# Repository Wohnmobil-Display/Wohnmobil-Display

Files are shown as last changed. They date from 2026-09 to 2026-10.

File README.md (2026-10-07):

# Wohnmobil-Display – dein Wohnmobil immer im Blick

**Alles wird überwacht – und du bekommst eine Nachricht aufs Handy, wenn etwas nicht stimmt.**

Ein 7-Zoll-Touchdisplay, das rund um die Uhr auf dein Wohnmobil aufpasst:

- 🔋 **Spannung und Ladezustand** von Starter- und Aufbau-Batterie, jede einzelne Zelle des JK-BMS
- ☀️ **Solarertrag** vom Victron-Laderegler, heute und die letzten 7 Tage
- 💧 **Frisch- und Abwasser** – Warnung, bevor der Tank leer bzw. voll ist
- 🔥 **Gasflaschen** in Prozent – Warnung, bevor das Gas ausgeht
- 🌡️ **Temperaturen** innen, außen und im Kühlschrank – Warnung bei zu warm oder zu kalt
- 🚨 **Alarmanlage** mit Tür-, Fenster- und Bewegungsmeldern, **Rauch- und Gasmelder** rund um die Uhr
- 📱 **Push-Nachrichten per Telegram** für jede Warnung – du entscheidest, worüber du informiert werden willst
- 🗓️ **Tagesbericht per Telegram:** einmal am Tag zur Wunschzeit alle wichtigen Werte aufs Handy – Batterien, Tanks, Gas, Solar, Temperaturen, Alarm (ab dem nächsten Update)
- 📡 **Sensor offline oder Batterie schwach?** Auch das meldet das Display

Es ersetzt das originale Schaudt-Bedienteil **LT 100** und nutzt dessen **vorhandene Stecker und Kabel**.
Zum Ausprobieren läuft es **72 Stunden kostenlos und ohne Einschränkung**.

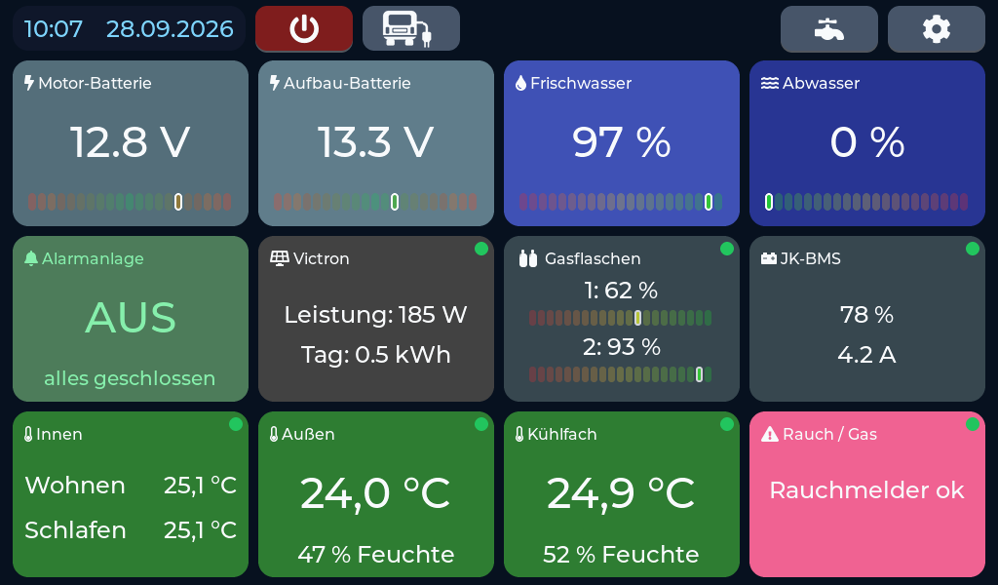
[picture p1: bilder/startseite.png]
Startseite


**Inhalt:** [Funktionen](#funktionen) · [Bedienung](#bedienung) · [Hardware](#hardware) · [Einkaufsliste](#einkaufsliste) ·
[Installation](#1-installation) · [Testzeit](#2-erster-start-testzeit) · [Freischalten](#3-freischalten) · [Updates](#4-updates)

## Funktionen

| Bereich | Was das Display kann |
|---|---|
| **Batterien** | Motor- und Aufbau-Batterie, JK-BMS mit allen 12 Zellen, Temperaturen und Ladezustand (Bluetooth) |
| **Solar** | Victron-MPPT-Laderegler: Leistung, Tagesertrag, Verlauf der letzten 7 Tage (Bluetooth) |
| **Wasser** | Frischwasser über den Original-Geber oder Ultraschall, Abwasser über die Original-Elektrodenstäbe |
| **Pumpe** | Wasserpumpe per Fingertipp ein/aus, automatisch gesperrt bei scharfer Alarmanlage |
| **Gas** | Zwei Gasflaschen mit Mopeka-Pro-Sensoren in Prozent (Bluetooth) |
| **Temperatur** | Innen (Wohn- und Schlafbereich), außen, Kühlschrank – über Zigbee-Sensoren oder fest verbaute Fühler |
| **Alarmanlage** | Bis zu 12 Zigbee-Sensoren (Tür/Fenster, Bewegung, Wasser), Nachtmodus, Verlassens-/Eingangszeit, PIN, Summer, Sirene |
| **Rauch / Gas** | Zigbee-Melder, rund um die Uhr überwacht |
| **Landstrom** | Anzeige, ob 230 V anliegen |
| **Push-Nachrichten** | Alarm, Grenzwerte, schwache Batterien, Sensor offline – per Telegram aufs Handy |
| **Tagesbericht** | täglich zur eingestellten Uhrzeit eine Zusammenfassung per Telegram, Inhalte frei wählbar (ab dem nächsten Update) |
| **Komfort** | Kachelnamen und Farben frei wählbar, Nachtabschaltung, Näherungssensor weckt das Display, Einstellen per Handy-Webseite |
| **Updates** | Neue Versionen per WLAN direkt am Display |

## Bedienung

Die komplette **[Bedienungsanleitung (PDF)](docs/Bedienungsanleitung.pdf)** zeigt jede Seite und jede Einstellung.

| Alarmanlage ein-/ausschalten | Victron / Solar mit 7-Tage-Verlauf |
|---|---|
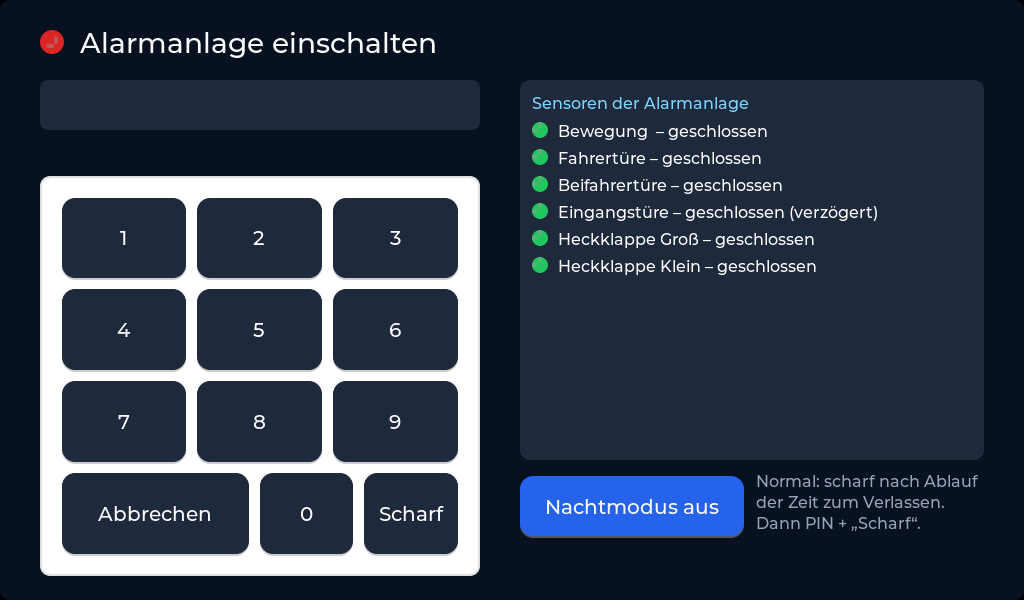
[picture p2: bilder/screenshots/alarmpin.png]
PIN-Dialog
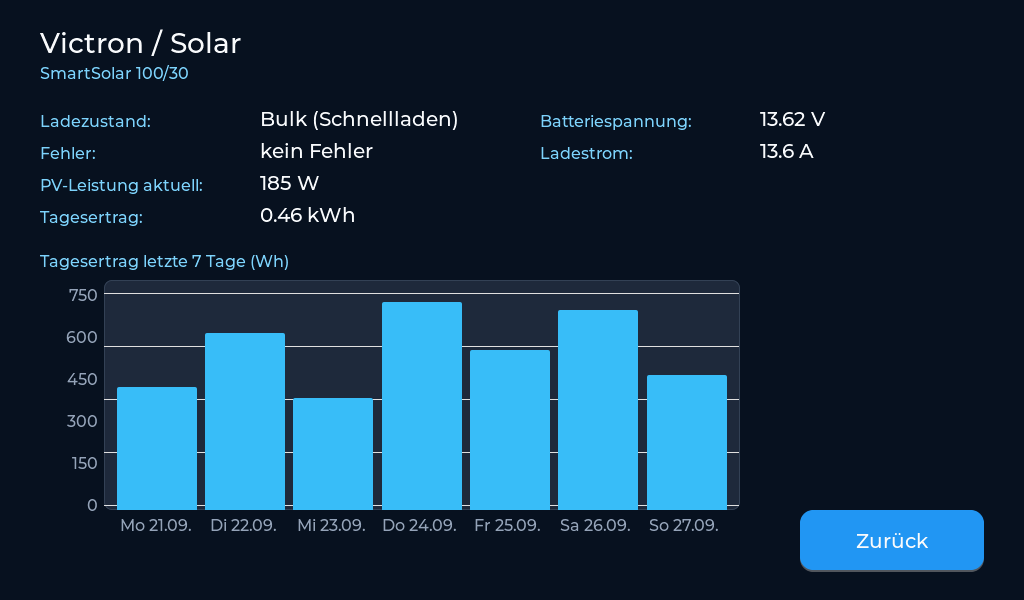
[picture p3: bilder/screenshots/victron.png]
Victron
|  |  |
| **JK-BMS mit Zellspannungen** | **Zigbee-Geräte** |
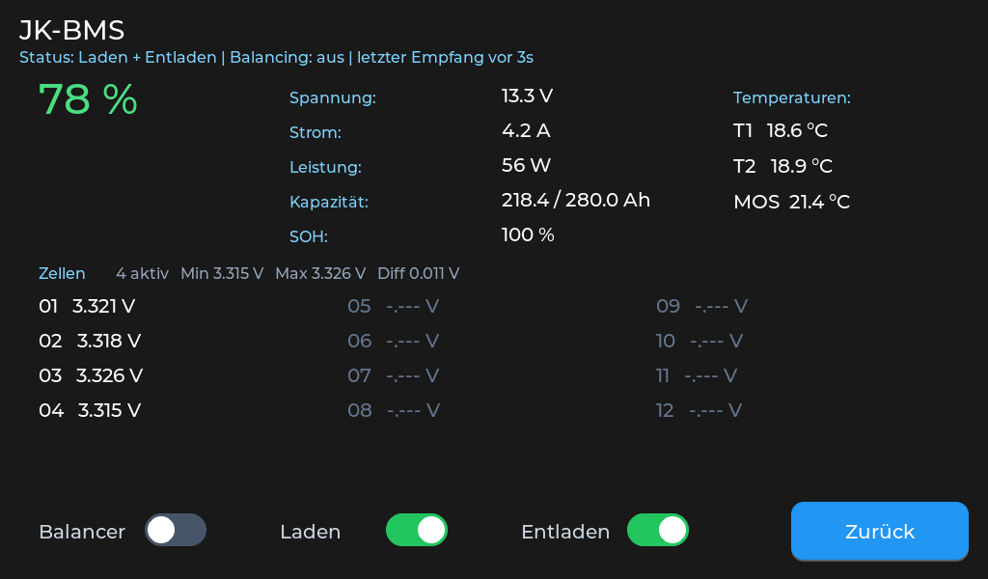
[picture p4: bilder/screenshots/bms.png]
JK-BMS
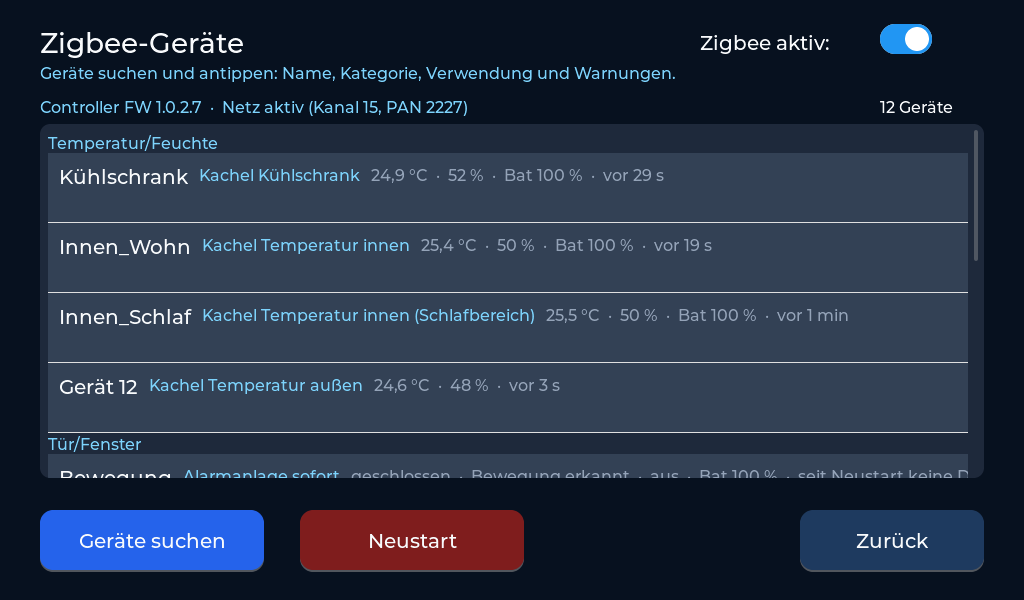
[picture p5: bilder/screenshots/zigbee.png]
Zigbee
|  |  |
| **Setup Alarmanlage** | **Setup Display** |
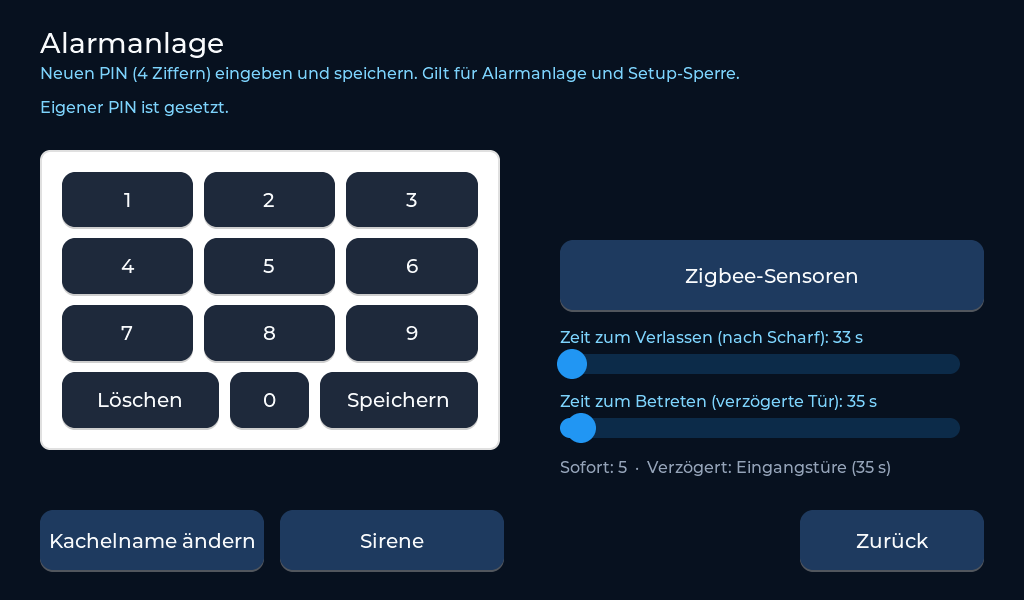
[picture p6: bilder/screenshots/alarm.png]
Setup Alarmanlage
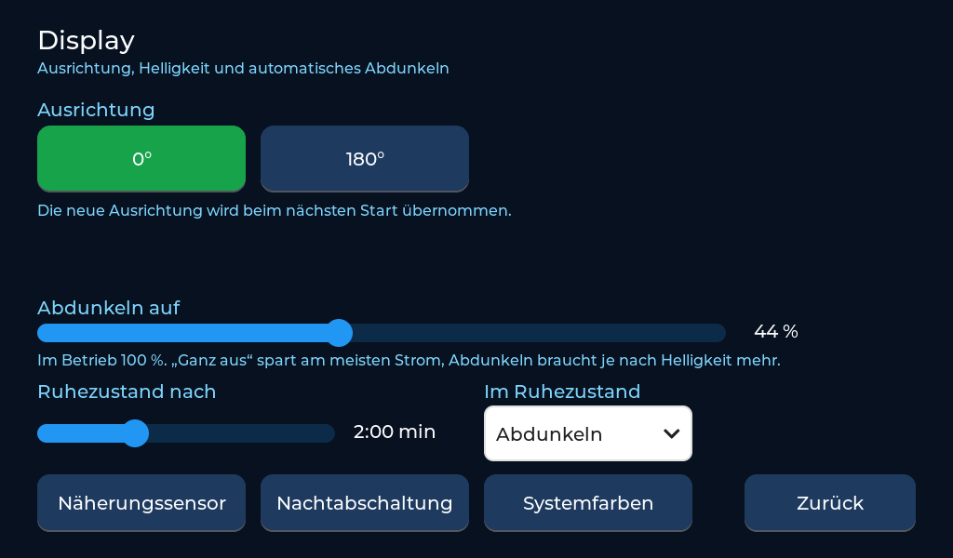
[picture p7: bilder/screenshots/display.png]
Setup Display
|  |  |
| **Setup Push-Nachrichten** | **Tagesbericht per Telegram** |
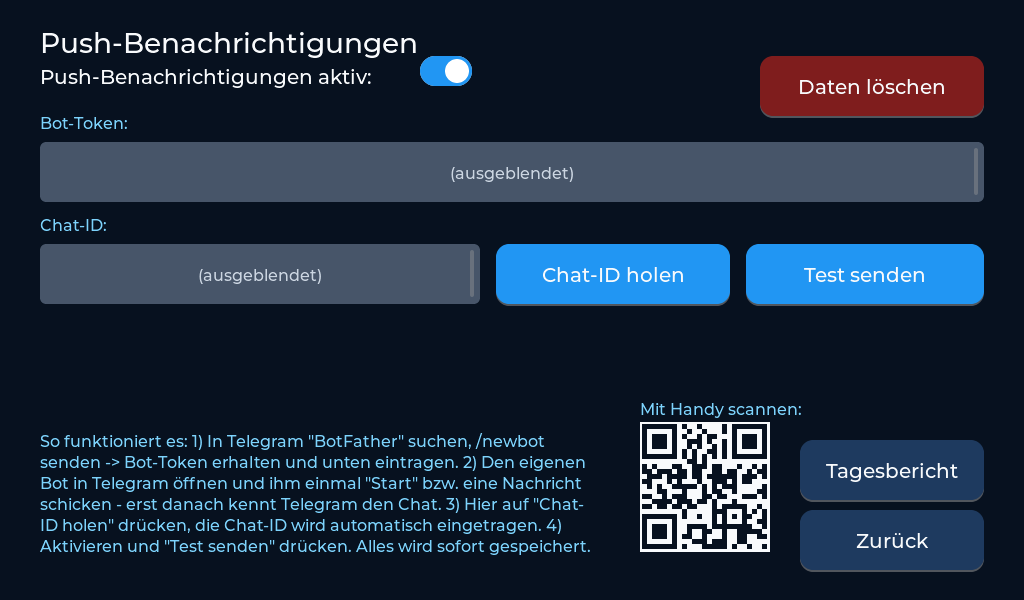
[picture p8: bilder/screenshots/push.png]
Setup Push
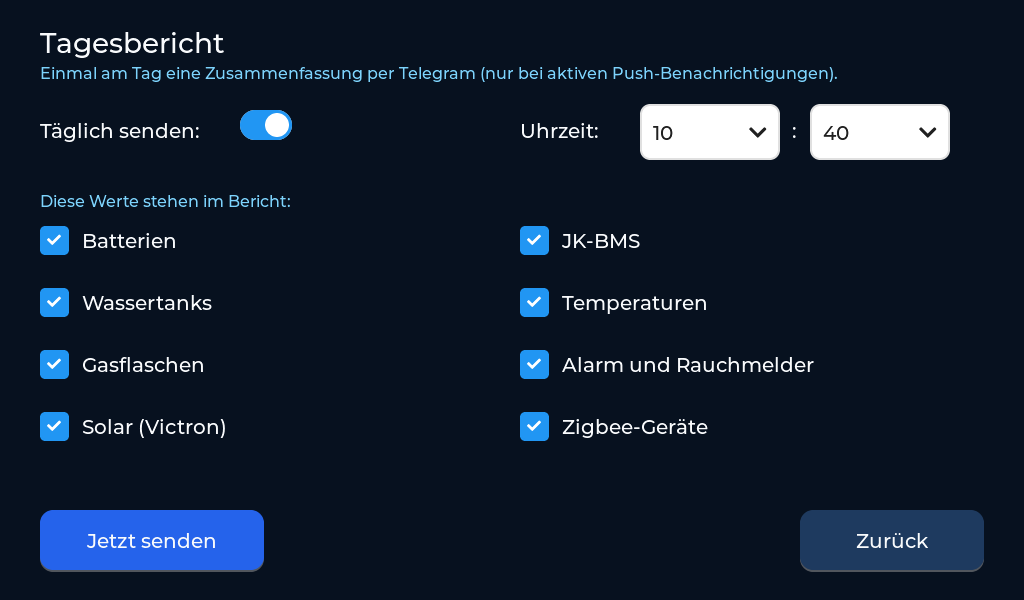
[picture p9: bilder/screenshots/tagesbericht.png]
Tagesbericht
|  |  |
| **Setup Victron-Laderegler** | |
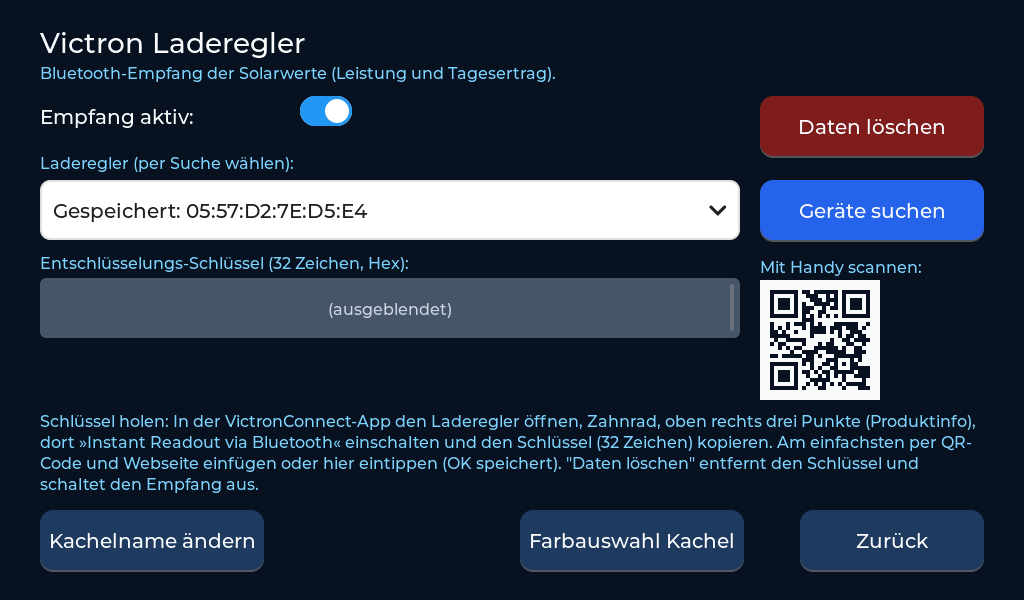
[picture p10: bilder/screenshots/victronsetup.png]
Setup Victron
|  | |

*Victron- und BMS-Seite mit Beispielwerten; Bot-Token, Chat-ID und Victron-Schlüssel sind im Bild ausgeblendet.*

- **Startseite:** 12 Kacheln, oben Uhrzeit, Landstrom, Störmeldungen, Wasserpumpe und Setup.
- **Rote Kachel:** ein eingestellter Grenzwert ist verletzt (z. B. Frischwasser fast leer).
- **Antippen** öffnet Detailseiten (Solar, BMS, Temperaturen) bzw. die PIN-Eingabe der Alarmanlage.
- **Setup:** keine Speichern-Taste – alles wird sofort gespeichert.

## Hardware

Systemübersicht

Das System besteht aus dem **Display** und der **Steuerplatine** – beide sind nötig.
Die **Relaisplatine** für die Wasserpumpe ist eine Erweiterung, die man weglassen kann.

- **Display:** Waveshare ESP32-S3-Touch-LCD-7B (7 Zoll, 1024×600, WLAN, Bluetooth).
  Bluetooth-Geräte (Victron, Mopeka, JK-BMS) empfängt es direkt.
- **3D-Druckteile** im Ordner [`druck/`](druck/): **Rahmen für das Display** (ersetzt das LT 100 im vorhandenen Ausschnitt, mit oder ohne Näherungssensor), **Halter für Türkontakte** (Sensor und Magnet, verschiedene Sockelhöhen) und **Gehäuse** für Steuer- und Relaisplatine.

### Steuerplatine – notwendig

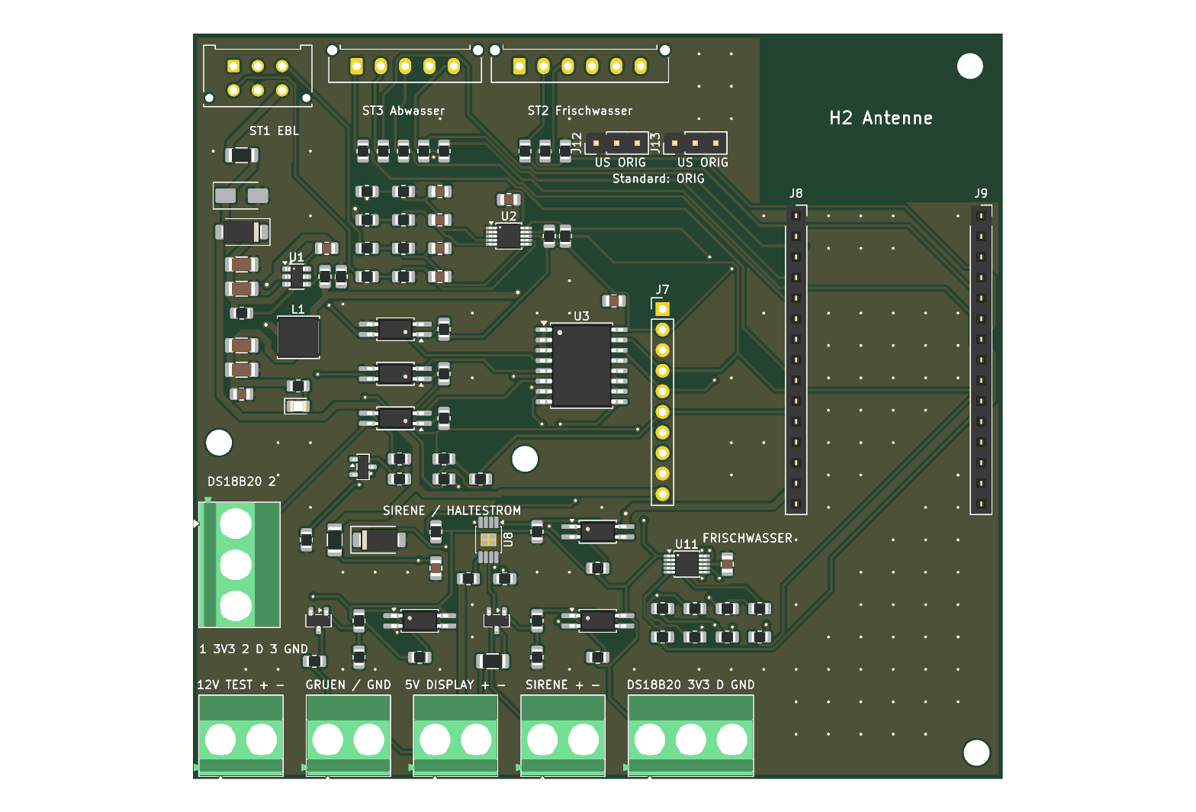
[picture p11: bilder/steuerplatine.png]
Steuerplatine


Die Steuerplatine ist die Verbindung zwischen Display und Fahrzeug. Sie sitzt dort, wo vorher das LT 100 war,
und bekommt **die vorhandenen Original-Stecker** – es muss kein neues Kabel durchs Fahrzeug gezogen werden.
Auf ihr steckt das **ESP32-H2-Board**, das die Messwerte erfasst und das **Zigbee-Funknetz** betreibt.
Mit dem Display ist sie über **ein USB-Kabel** verbunden.

| Anschluss | Was angeschlossen wird |
|---|---|
| **ST1 – EBL** (Original-Stecker) | Stromversorgung 12 V, Hauptschalter **EIN/AUS**, 12-V-Kontrolle, **Landstrom** (230 V liegt an) |
| **ST2 – Frischwasser** (Original-Stecker) | Originaler Tankgeber (Stabsonde) **oder** Ultraschallsensor – umschaltbar per Steckbrücke |
| **ST3 – Abwasser** (Original-Stecker) | Originale Elektrodenstäbe (25 / 50 / 75 / 100 %) |
| **Klemme GRÜN** | Freie grüne Ader im Panelkabel: misst die **Starterbatterie** und schaltet die Relaisplatine |
| **Klemme 5V DISPLAY** | Versorgt das Display – ein eigenes Netzteil ist nicht nötig |
| **Klemme SIRENE** | Alarmsirene (überwacht auf Kurzschluss und offene Leitung) |
| **Klemmen DS18B20** | Fest verbaute Temperaturfühler (z. B. innen, Kühlschrank) |
| **USB** | Verbindung zum Display |

Gemessen werden Starter- und Aufbau-Batterie, 12-V-Kontrolle und Landstrom.
**Ohne Steuerplatine** zeigt das Display nur die Bluetooth-Geräte – Tanks, Hauptschalter, Landstrom,
Pumpe und alle Zigbee-Sensoren (Alarmanlage, Rauchmelder, Temperaturen) funktionieren dann nicht.

**Frischwasser mit Ultraschallsensor** – die vorhandene Leitung der Füllstandsstäbe wird weiterbenutzt,
am Tank wird der alte Stecker abgeschnitten und die Adern nach Farbe an die Sensorplatine gelötet,
auf der Steuerplatine werden nur die beiden Steckbrücken J12/J13 auf „US“ gesteckt:

Ultraschallsensor an der Steuerplatine

### Relaisplatine für die Frischwasserpumpe – optional

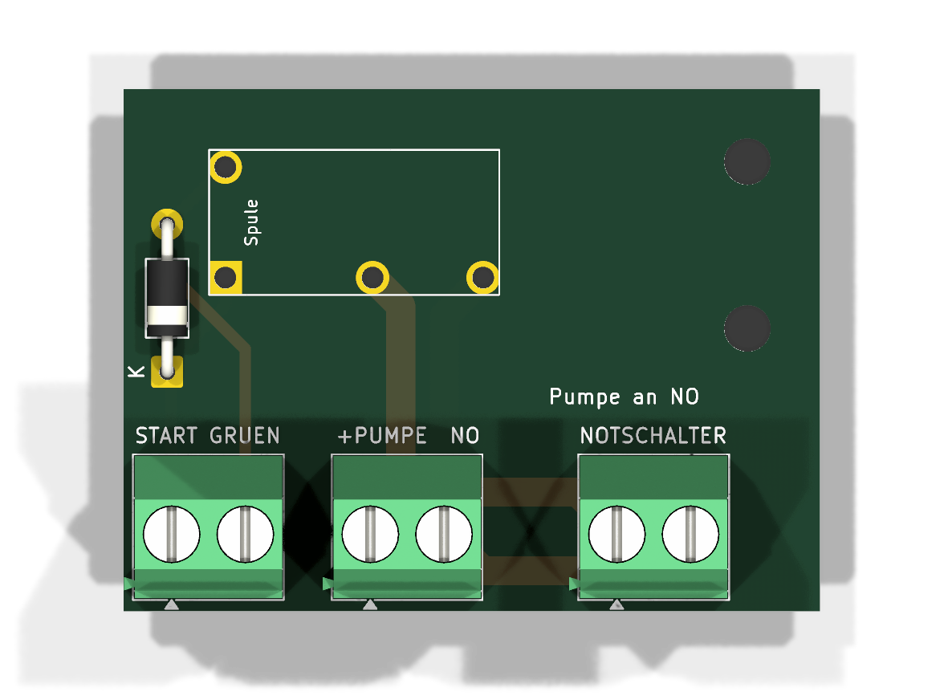
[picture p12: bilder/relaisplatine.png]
Relaisplatine


Beim originalen LT 100 lässt sich die Wasserpumpe nicht schalten – hier schon:

- **Pumpe per Fingertipp ein/aus** über das Wasserhahn-Symbol oben auf der Startseite.
- **Automatisch aus, wenn die Alarmanlage scharf ist** – kein Wasser läuft unbemerkt, während du weg bist.
- **Anschluss für einen Notschalter**: überbrückt das Relais, falls einmal etwas nicht funktioniert – die Pumpe läuft dann wie früher.
- Die Platine wird am EBL in die Plus-Leitung der Pumpe eingesetzt und über die grüne Ader von der Steuerplatine geschaltet.

**Keine Relaisplatine?** Unter *Setup → Allgemein → Wasserpumpe (Relaisplatine)* ausschalten –
dann verschwinden das Wasserhahn-Symbol und alle Pumpen-Meldungen, alles andere läuft weiter.

**Die Original-Stecker werden einfach umgesteckt – kein neues Kabel durchs Fahrzeug:**

| LT 100 mit den Original-Steckern | Stecker abgezogen |
|---|---|
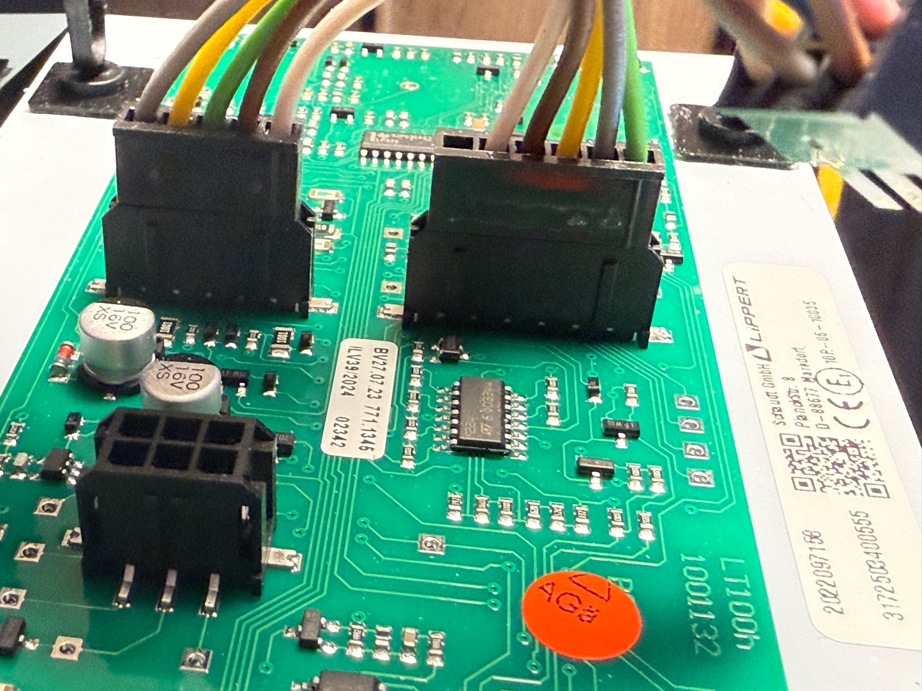
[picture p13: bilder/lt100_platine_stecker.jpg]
LT 100 Platine
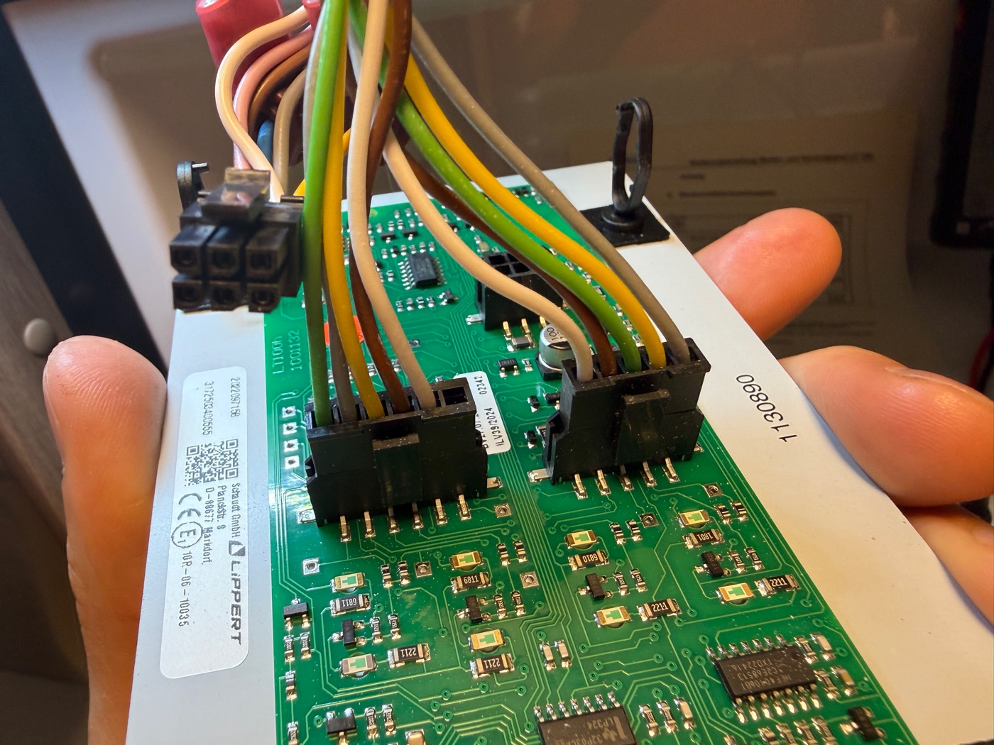
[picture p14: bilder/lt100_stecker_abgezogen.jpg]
Stecker abgezogen
|  |  |

| Kabel zum EBL (ST1) | EBL 31, Block 3 „Instr.-Tafel“ |
|---|---|
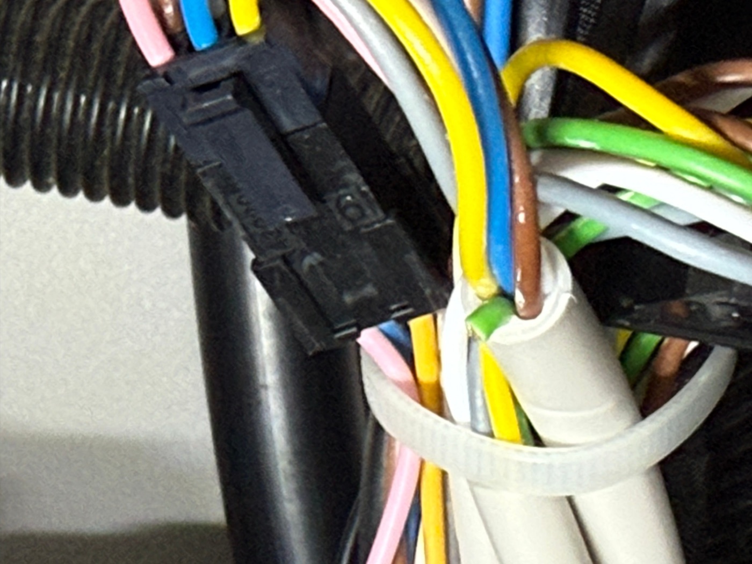
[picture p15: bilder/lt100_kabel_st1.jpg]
ST1
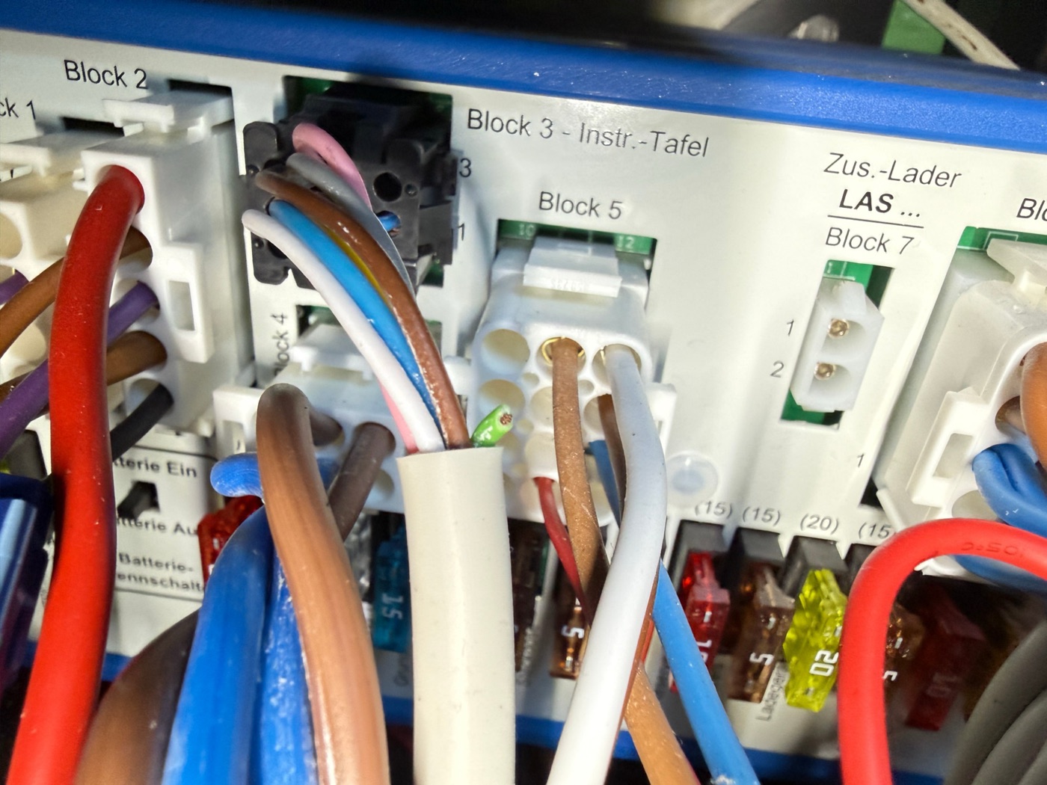
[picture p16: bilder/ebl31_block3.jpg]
EBL 31
|  |  |

Anschlüsse am Display:

Anschlüsse am Display

**Summer und Näherungssensor** kommen direkt an das Display (Buchsen J8 und H1). Die Stecker mit Kabel
sind vorhanden – nur die beiden Bauteile an die Kabelenden anlöten:

Summer und Näherungssensor am Display

## Einkaufsliste

| Teil | Wofür | Link |
|---|---|---|
| Waveshare ESP32-S3-Touch-LCD-7B (7 Zoll, 1024×600) | Das Display | [Amazon\*](https://www.amazon.de/dp/B0FG354VCN?tag=wohnmobildisp-21) |
| ESP32-H2-DevKitM-1 (N4) | Zigbee und Steuerplatine | [Amazon\*](https://www.amazon.de/dp/B0D8XR48LF?tag=wohnmobildisp-21) |
| Ultraschallsensor JSN-SR04M-2 / AJ-SR04M / A02YYPWM (wasserdicht) | Frischwasser (optional, statt Original-Geber) – funktioniert ohne Löten, wird automatisch erkannt | [Amazon\*](https://www.amazon.de/dp/B0FPPTTHTJ?tag=wohnmobildisp-21) |
| frient Smoke Alarm (Zigbee-Rauchmelder mit Sirene) | Rauchmelder, auch als Alarm-Sirene nutzbar | [Amazon\*](https://www.amazon.de/dp/B08WXV3G8P?tag=wohnmobildisp-21) |
| SONOFF SNZB-02B (Zigbee-Temperatur/Luftfeuchte) | Temperatur innen, außen, Kühlschrank | [Amazon\*](https://www.amazon.de/dp/B0H4QJQFKM?tag=wohnmobildisp-21) |
| SONOFF SNZB-04P (Zigbee-Tür-/Fensterkontakt) | Alarmanlage | [Amazon\*](https://www.amazon.de/dp/B0DD3SQYV9?tag=wohnmobildisp-21) |
| SONOFF SNZB-03P (Zigbee-Bewegungsmelder) | Alarmanlage | [Amazon\*](https://www.amazon.de/dp/B0C1GB4DVR?tag=wohnmobildisp-21) |
| Mopeka Pro (Ultraschallsensor mit Magnet) | Gasflaschen-Füllstand (optional) | [Amazon\*](https://www.amazon.de/dp/B0GCD1Q4HP?tag=wohnmobildisp-21) |
| VL53L0X-Näherungssensor (2 Stück) | Display wird hell, wenn jemand davor steht (optional) – getestet, funktioniert sofort | [Amazon\*](https://www.amazon.de/dp/B0FPQRKR9T?tag=wohnmobildisp-21) |
| Steckverbinder-Set 6-polig MATE-N-LOK (Kalitec KALI-1106, 6,35 mm, inkl. Crimpkontakte und Dichtungen, bis 19 A) | 12-V-Dauerspannung am EBL-Stecker Block 5 Pin 3 abgreifen (dort liegt auch der Wassertank-Anschluss): Crimpkontakt auf die Ader, in den freien Platz am EBL-Stecker einstecken | [Amazon\*](https://www.amazon.de/dp/B0DP58HVVM/?tag=wohnmobildisp-21) |
| USB-C-Datenkabel (240 W, Set: 1 m + 1 m + 1,5 m + 1,5 m) | Verbindung Display ↔ Steuerplatine und Anschluss am Computer – reines Ladekabel funktioniert nicht | [Amazon\*](https://www.amazon.de/dp/B0GX5WF5B9/?tag=wohnmobildisp-21) |
| Schrauben M3 × 8 mm (100 Stück, Edelstahl, Flachkopf, vollgewinde) | Montage | [Amazon\*](https://www.amazon.de/dp/B0FHGSGFY4/?tag=wohnmobildisp-21) |

\* Werbelink: Als Amazon-Partner verdiene ich an qualifizierten Verkäufen. Für dich ändert sich am Preis nichts.

## 1. Installation

Die Firmware wird direkt im Browser installiert – ohne Download und ohne Zusatzprogramm.

**Du brauchst:**
- ein USB-Datenkabel (ein reines Ladekabel funktioniert nicht),
- einen Computer mit **Google Chrome** oder **Microsoft Edge**,
- kein anderes Programm, das gerade auf den USB-Anschluss zugreift (z. B. Arduino IDE, serieller Monitor).

Es werden **zwei Geräte** installiert – beide auf derselben Installer-Seite, jedes mit eigenem Knopf:

| Gerät | Anschluss am Computer | Direkt zum Knopf |
|---|---|---|
| **① Display** (Waveshare 7 Zoll) | USB-C-Buchse **„UART1“** am Display (Schalter SW1 auf „UART1“) | **[Display installieren](https://wohnmobil-display.github.io/Wohnmobil-Display/#display)** |
| **② Steuerplatine** (ESP32-H2-Board) | Buchse **„USB“** am H2-Board (nicht „UART“), einmal **vor dem Einbau** | **[Steuerplatine installieren](https://wohnmobil-display.github.io/Wohnmobil-Display/#steuerplatine)** |

Welche Buchse wofür – Display-Rückseite und H2-Board

Display und Steuerplatine verbinden

> **Wichtig – Jumper J5 am H2-Board:** Die kleine Steckbrücke (Jumper) muss auf den beiden Stiften **J5** stecken.
> Ohne sie bekommt der Chip keinen Strom – er wird am Computer nicht erkannt und läuft auch auf der Steuerplatine nicht.
> Liegt der Jumper lose in der Packung, einfach aufstecken.

**So geht's (für beide Geräte gleich):**
1. Link oben anklicken – die Installer-Seite öffnet sich beim passenden Knopf.
2. Gerät per USB anschließen und auf **Display installieren** bzw. **Steuerplatine installieren** klicken.
3. Im Fenster den Eintrag des Geräts wählen (z. B. „USB JTAG/serial debug unit“ oder „USB Single Serial“) und auf **Verbinden** klicken.
4. Installation bestätigen und warten, bis sie fertig ist. Kabel nicht abziehen, Browser nicht schließen.
5. Das Gerät startet danach von selbst neu. Falls nicht: kurz vom Strom trennen und wieder anschließen.

Die Steuerplatine muss nur **ein einziges Mal** so installiert werden. Spätere Updates spielt das Display
selbst über das USB-Kabel auf (siehe [Updates](#4-updates)).

> Wird kein Gerät angezeigt, probiere ein anderes Kabel oder einen anderen USB-Anschluss.
> Stecke das Gerät kurz ab und wieder an und wähle dann den neu erschienenen Eintrag.

## 2. Erster Start: Testzeit

Beim ersten Start zeigt das Display den Bildschirm **Freischaltung** mit zwei Werten:

- **Chip-ID**, z. B. `AA:BB:CC:DD:EE:FF`
- **Freigabecode**, z. B. `1234`

Darunter steht die fertige Zeile zum Freischalten, z. B.:

```
AA:BB:CC:DD:EE:FF 1234
```

Mit **„Test starten (72 Std.)“** kannst du das Display 72 Betriebsstunden lang kostenlos und uneingeschränkt nutzen.
Gezählt wird nur die Zeit, in der das Display eingeschaltet ist. Die restliche Testzeit steht oben in der Kopfzeile.
Nach Ablauf zeigt das Display nur noch den Freischalt-Bildschirm.

## 3. Freischalten

Das Wohnmobil-Display ist ein privat entwickeltes Hobbyprojekt. Für die dauerhafte Nutzung ist ein persönlicher,
6-stelliger **Freischaltcode** nötig. Er kostet einmalig **29 €** und gilt für immer – auch nach Neustarts und Updates.

1. Öffne den PayPal-Link: **[paypal.com/ncp/payment/MHXFBPU9TVV2L](https://www.paypal.com/ncp/payment/MHXFBPU9TVV2L)**
2. Trage im Feld **„Chip-ID + Freigabecode“** die Zeile vom Display ein – genau so, wie sie dort steht:
   `AA:BB:CC:DD:EE:FF 1234`
3. Nach Eingang der Zahlung bekommst du den Freischaltcode per E-Mail, in der Regel **innerhalb von 24 Stunden**.
4. Gib den Code am Display ein und bestätige mit **OK**. Fertig – das Display ist dauerhaft freigeschaltet.

Den Freischalt-Bildschirm erreichst du während der Testzeit auch über **Setup → Allgemein → Freischaltung**.

> Feld beim Bezahlen vergessen? Schick die Zeile einfach an **wohnmobil.display@gmail.com**.
>
> Nach jeder dritten falschen Eingabe wird die Eingabe für einige Stunden gesperrt – den Code bitte genau übernehmen.

## 4. Updates

Freigeschaltete Displays holen neue Versionen selbst über WLAN – **für das Display und für die Steuerplatine**:
**Setup → Allgemein → Update → Installieren.**
Die Steuerplatine wird dabei über das USB-Kabel vom Display aus aktualisiert – nichts muss ausgebaut werden.
Deine Einstellungen bleiben dabei erhalten. Startet eine neue Version einmal nicht richtig,
kehrt das Display automatisch zur vorherigen Version zurück.

Was sich geändert hat, steht bei den [Versionen (Releases)](https://github.com/Wohnmobil-Display/Wohnmobil-Display/releases).

## Hilfe bei Verbindungsproblemen

- Nur Chrome oder Edge verwenden.
- Ein anderes USB-Kabel und einen anderen USB-Anschluss probieren.
- Alle Programme schließen, die den USB-Anschluss benutzen könnten.
- Display kurz abziehen und wieder anschließen, Installer-Seite neu laden.

## Manuelle Installation

Falls die Installer-Seite nicht funktioniert: Unter [Releases](https://github.com/Wohnmobil-Display/Wohnmobil-Display/releases)
liegen zwei Dateien, die mit einem eigenen Flash-Programm jeweils an **Adresse 0x0** geschrieben werden:
- `Wohnmobil-Display-FULL.bin` → Display
- `Steuerplatine-H2-FULL.bin` → Steuerplatine (ESP32-H2, Buchse „USB“)

Die Dateien ohne „FULL“ sind nur für Updates gedacht.

## Hinweis

Das Wohnmobil-Display ist ein privates DIY-Projekt ohne Firma dahinter und steht in keiner Verbindung zu Schaudt,
Waveshare, Victron, Mopeka oder anderen Herstellern der unterstützten Geräte. Die Nutzung erfolgt auf eigene Verantwortung.

Kontakt: **wohnmobil.display@gmail.com**

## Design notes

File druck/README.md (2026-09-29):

# Druckdateien (3D-Druck)

| Teil | Dateien | Außenmaß (B × T × H) |
|---|---|---|
| Gehäuse Steuerplatine V2 | [Unterschale](steuerplatine_v2_unterschale.stl) · [Deckel](steuerplatine_v2_deckel.stl) | 127 × 112 × 34 mm (mit Laschen) |
| Gehäuse Relaisplatine V2 | [Unterschale](relaisplatine_v2_unterschale.stl) · [Deckel](relaisplatine_v2_deckel.stl) | 75 × 56 × 30 mm (mit Laschen) |
| Rahmen für das Display (7 Zoll) – ersetzt das alte LT-100-Panel | [mit Näherungssensor](display_rahmen_mit_sensor.stl) · [ohne Sensor](display_rahmen_ohne_sensor.stl) | 193 × 123 × 27 mm / 193 × 111 × 27 mm |
| Türkontakt-Halter Standard, 2-mm-Boden (nur Kleben) | [Sensorhalter](tuerkontakt_sensorhalter_standard.stl) · [Magnethalter](tuerkontakt_magnethalter_standard.stl) | 94 × 15 × 28 mm / 50 × 9 × 16 mm |
| Türkontakt-Halter mit 5 mm Abstand (Kleben oder Schrauben) | [Sensorhalter](tuerkontakt_sensorhalter_5mm.stl) · [Magnethalter](tuerkontakt_magnethalter_5mm.stl) | 94 × 20 × 28 mm / 50 × 14 × 16 mm |
| Türkontakt-Halter mit 10 mm Abstand (Kleben oder Schrauben) | [Sensorhalter](tuerkontakt_sensorhalter_10mm.stl) · [Magnethalter](tuerkontakt_magnethalter_10mm.stl) | 94 × 25 × 28 mm / 50 × 19 × 16 mm |

**Drucken:** PLA oder PETG, 0,2 mm Schichthöhe, 3 Wände. Die Gehäuse und Türkontakt-Halter gehen ohne Stützmaterial
(Unterschale mit dem Boden nach unten, Deckel mit der Oberseite nach unten). **Der Rahmen für das Display braucht Stützstruktur.**
Die Kabelschlitze der Gehäuse sind oben offen, die Zungen am Deckel schließen sie bis auf den Kabelspalt.

**Montage:**
- Platine mit M3-Schrauben (selbstschneidend, ca. 8 mm) auf die Stehbolzen schrauben.
- Deckel mit 4 × M3 (ca. 16 mm) in die Eckpfosten schrauben.
- Gehäuse über die seitlichen Laschen (Loch 4,5 mm) an Wand oder Möbel schrauben.

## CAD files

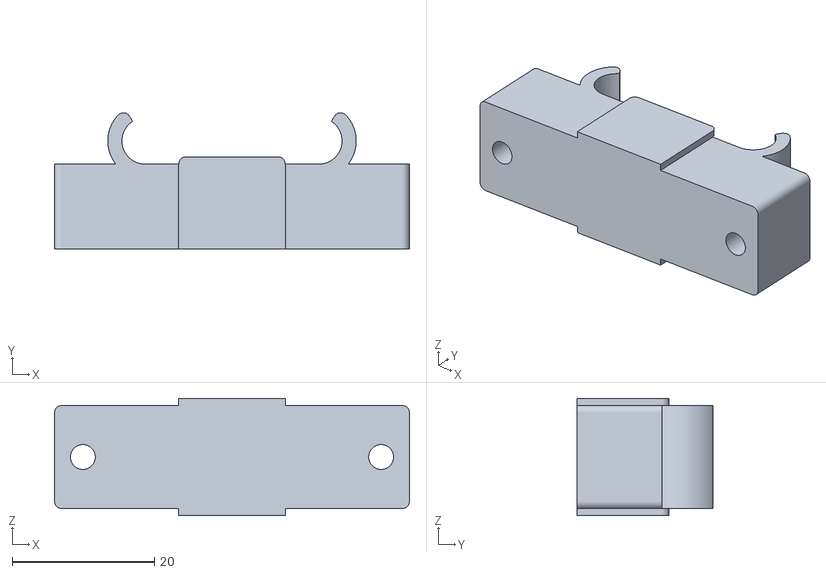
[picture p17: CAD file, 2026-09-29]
druck/tuerkontakt_magnethalter_10mm.stl
50.0 x 19.2 x 16.5

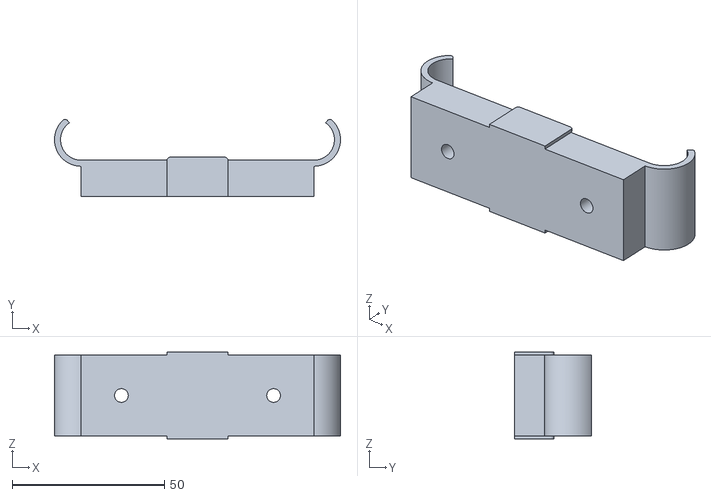
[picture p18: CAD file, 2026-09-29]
druck/tuerkontakt_sensorhalter_10mm.stl
94.0 x 25.4 x 28.5

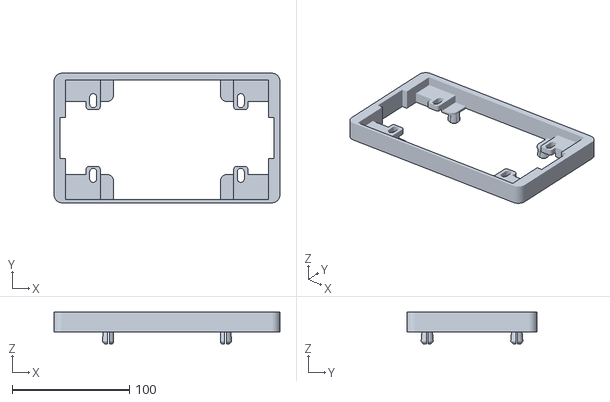
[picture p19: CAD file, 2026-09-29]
druck/display_rahmen_ohne_sensor.stl
193.0 x 110.8 x 27.0

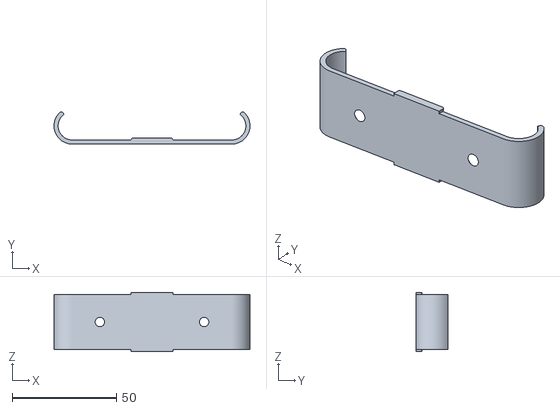
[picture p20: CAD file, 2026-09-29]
druck/tuerkontakt_sensorhalter_standard.stl
94.0 x 15.4 x 28.5

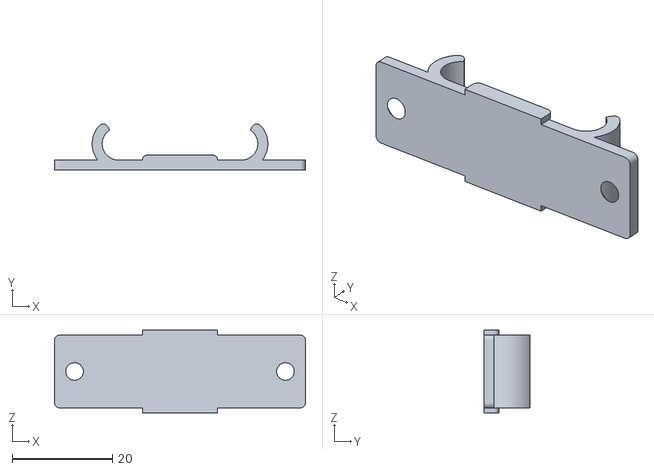
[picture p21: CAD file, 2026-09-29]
druck/tuerkontakt_magnethalter_standard.stl
50.0 x 9.21 x 16.5

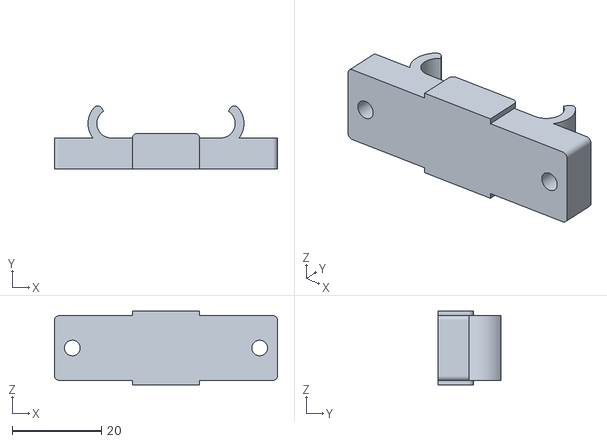
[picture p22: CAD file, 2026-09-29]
druck/tuerkontakt_magnethalter_5mm.stl
50.0 x 14.2 x 16.5

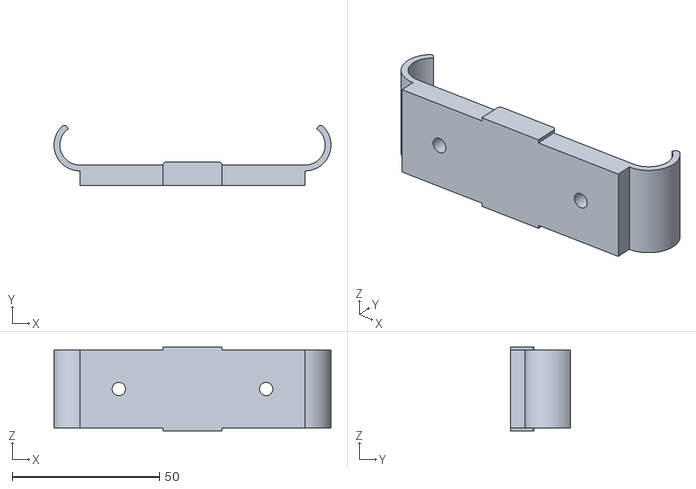
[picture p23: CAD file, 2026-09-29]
druck/tuerkontakt_sensorhalter_5mm.stl
94.0 x 20.4 x 28.5

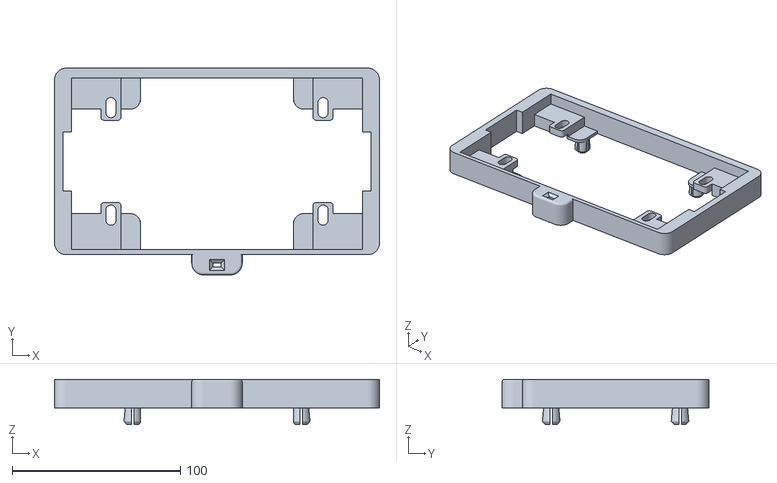
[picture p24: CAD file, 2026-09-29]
druck/display_rahmen_mit_sensor.stl
193.0 x 122.8 x 27.0

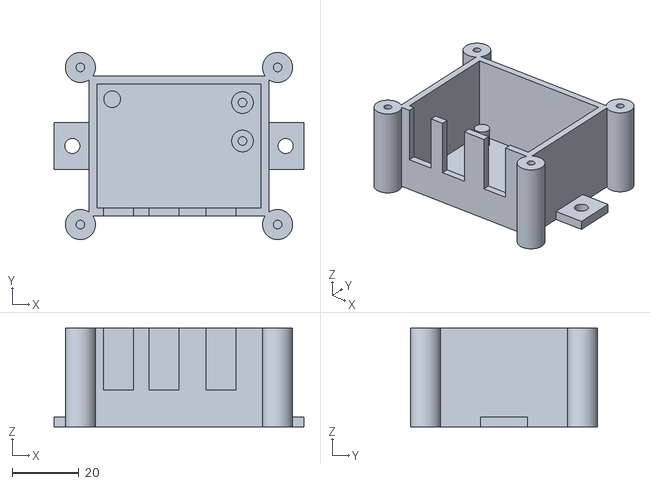
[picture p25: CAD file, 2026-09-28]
druck/relaisplatine_v2_unterschale.stl
74.8 x 56.0 x 29.6

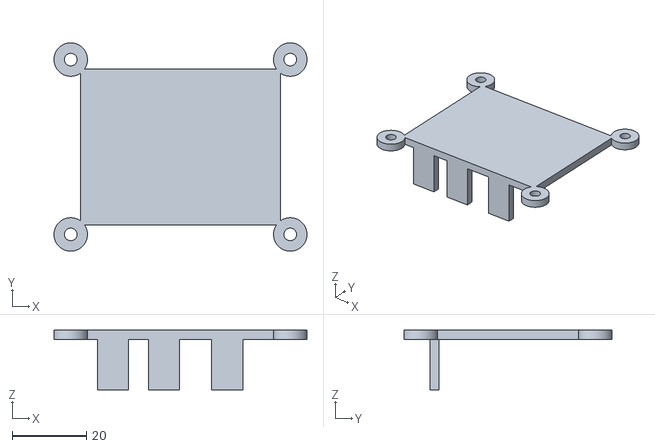
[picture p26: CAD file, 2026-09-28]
druck/relaisplatine_v2_deckel.stl
68.0 x 56.0 x 16.0

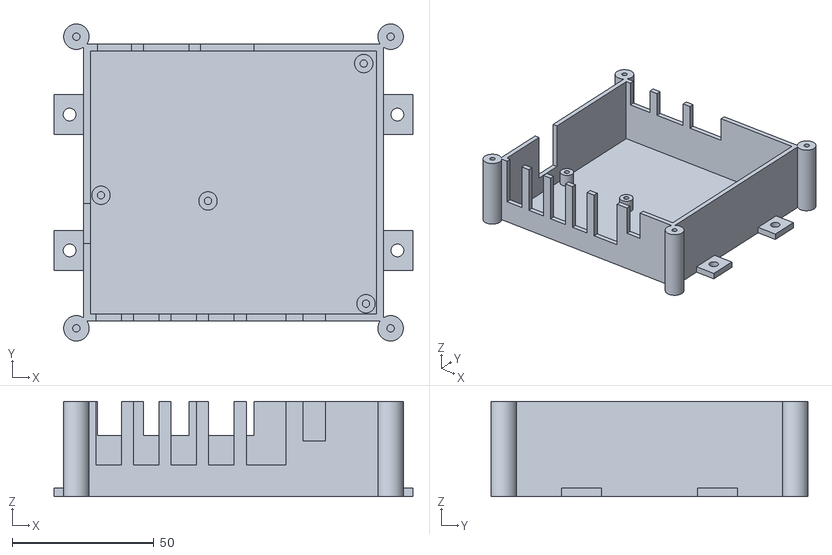
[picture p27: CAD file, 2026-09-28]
druck/steuerplatine_v2_unterschale.stl
126.8 x 112.0 x 33.6

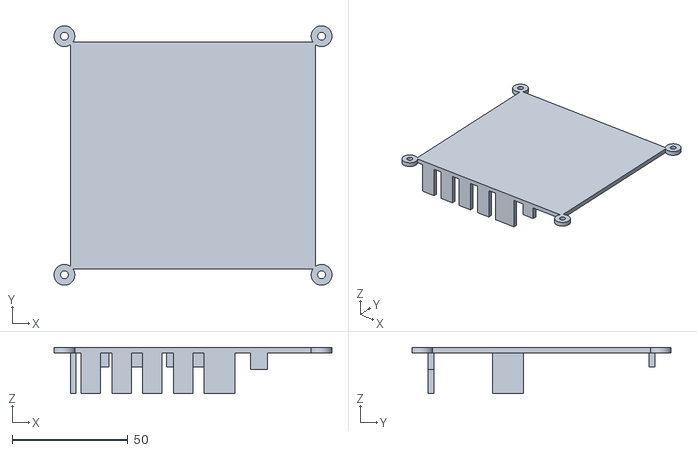
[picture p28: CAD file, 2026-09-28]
druck/steuerplatine_v2_deckel.stl
120.0 x 112.0 x 20.0

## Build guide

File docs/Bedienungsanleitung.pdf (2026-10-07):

# Wohnmobil-Display – Bedienungsanleitung

Bedienung aller Funktionen des 7-Zoll-Touch-Displays. Stand: 28.09.2026 (Display 1.0.8, Steuerplatine 1.0.3.0)

1. Erster Start und WLAN
2. Die Startseite
3. Alarmanlage
4. Das Setup-Menü – Grundregeln
5. Setup: Kacheln
6. Setup: System
7. Push-Nachrichten aufs Handy
8. Einstellen per Handy (Webseite)
9. Display ausschalten
10. Hilfe bei Problemen
11. Testzeit und Freischaltung
12. Updates
13. Druckteile (3D-Druck)

## 1. Erster Start und WLAN

1. Nach dem Einschalten sucht das Display nach WLAN-Netzen und zeigt sie als Liste an.
2. Netz antippen, das Passwort über die Bildschirmtastatur eingeben und Verbinden drücken. Mit der Taste äöü erreichst du Umlaute und Sonderzeichen.
3. Nach der Verbindung wechselt das Display automatisch zur Startseite. Das WLAN wird gespeichert und beim nächsten Start selbst verbunden.

Datum und Uhrzeit kommen automatisch aus dem Internet. Ohne WLAN zeigt die Uhr „--:--“.
Wird das WLAN nicht gefunden, erscheint oben im roten Meldungsfeld „Kein WLAN“. Ein anderes Netz richtest du unter Setup → WLAN-Einstellungen ein, dort gibt es auch WLAN löschen .

## 2. Die Startseite

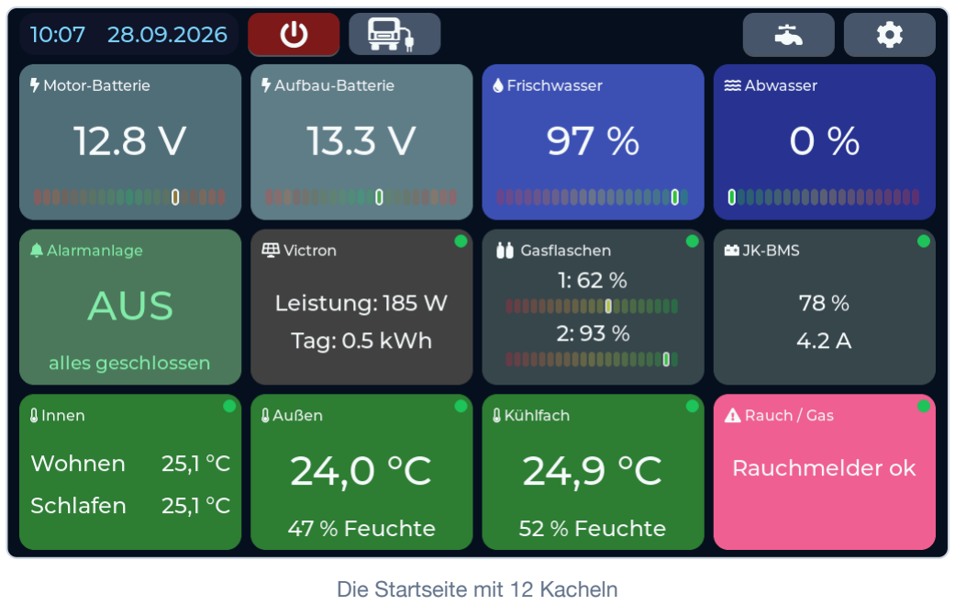
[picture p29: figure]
Die Startseite mit 12 Kacheln

Die Kopfzeile enthält von links nach rechts:

Feld | Bedeutung
Uhrzeit und Datum | aus dem Internet (WLAN)
rote Taste ⏻ | Display ausschalten (Abschnitt 9)
Landstrom (Wohnmobil mit Stecker) | gelb = 230-V-Landstrom liegt an (Netzkontrolle vom EBL), grau = kein Landstrom oder Steuerplatine nicht erreichbar
rotes Meldungsfeld | erscheint nur bei einer Störung, z. B. „Steuerplatine nicht erreichbar“, „Kein WLAN“, „Sensor offline: Name“, „Sirene: Kurzschluss oder Leitung offen“. Mehrere Meldungen wechseln alle 3 s, mit „(1/3)“.
Wasserhahn | Wasserpumpe: grün = frei, grau = gesperrt. Antippen fragt „Pumpe ein/aus?“. Bei scharfer Alarmanlage ist die Pumpe automatisch gesperrt.
Zahnrad | Setup

Darunter liegen 12 Kacheln:

Motor-Batterie Spannung | Aufbau-Batterie Spannung | Frischwasser Füllstand % | Abwasser Füllstand %
Alarmanlage Zustand, Tippen = PIN | Victron / Solar Leistung, Tagesertrag | Gas Flasche 1 und 2 in % | JK-BMS Ladezustand, Strom
Temperatur innen °C, Luftfeuchte; mit 2 Sensoren Wohnen/Schlafen | Temperatur außen °C, Luftfeuchte | Kühlschrank °C | Rauch / Gas Melder-Zustand

Rote Kachel: Ein eingestellter Grenzwert ist verletzt, zum Beispiel Frischwasser unter der Warnschwelle oder die Temperatur zu hoch.
Roter Punkt auf Temperatur-Kacheln: seit 10 Minuten keine Daten vom Sensor. Bei Rauch/Gas: Ein Melder ist nicht erreichbar.
„-- %“: Es liegt kein gültiger Messwert vor, zum Beispiel weil kein Sensor zugeordnet ist.
Antippen: Alarmanlage öffnet den PIN-Dialog. Victron, JK-BMS und alle Kacheln der unteren Reihe (Innen, Außen, Kühlschrank, Rauch/Gas) öffnen eine Detailseite mit allen Werten (Temperatur, Feuchte, Grenzwerte, Batterie, Funkqualität und letzte Meldung; innen Wohn- und Schlafbereich, Rauch/Gas beide Melder), bei Victron mit dem Tagesertrag der letzten 7 Tage. Zurück geht es über Zurück .
Namen und Farben der Kacheln lassen sich im Setup ändern (Abschnitt 4).

Motor- und Aufbau-Batterie misst die Steuerplatine (Starterbatterie über die grüne Ader, Aufbaubatterie über ST1). Ohne Messwert zeigt die Kachel „--.- V“ – dann gibt es auch keine Warnung. Ist ein JK-BMS eingerichtet, springt es für die Aufbaubatterie ein.

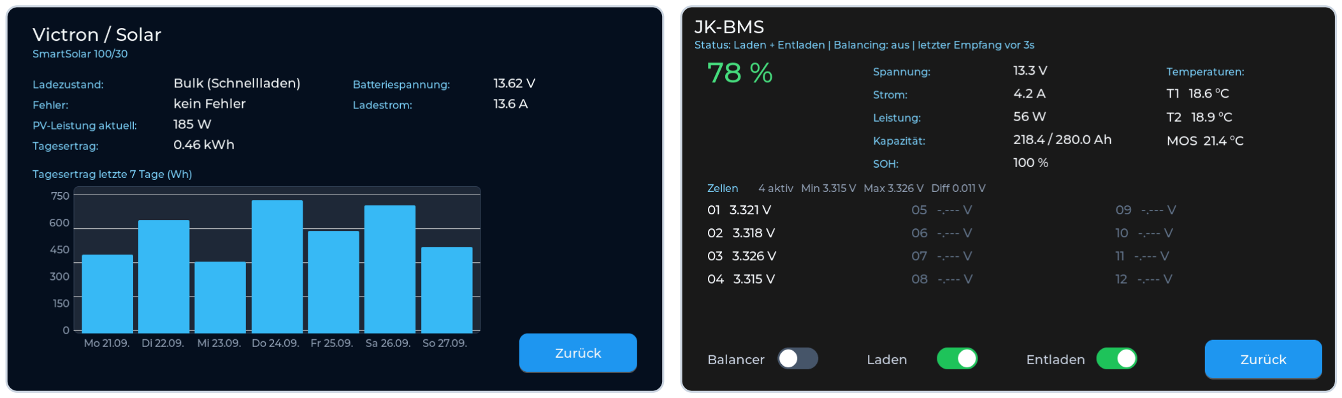
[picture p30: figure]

Detailseite Victron / Solar mit 7-Tage-Verlauf (Beispielwerte) Detailseite JK-BMS mit Zellspannungen (Beispielwerte)

## 3. Alarmanlage

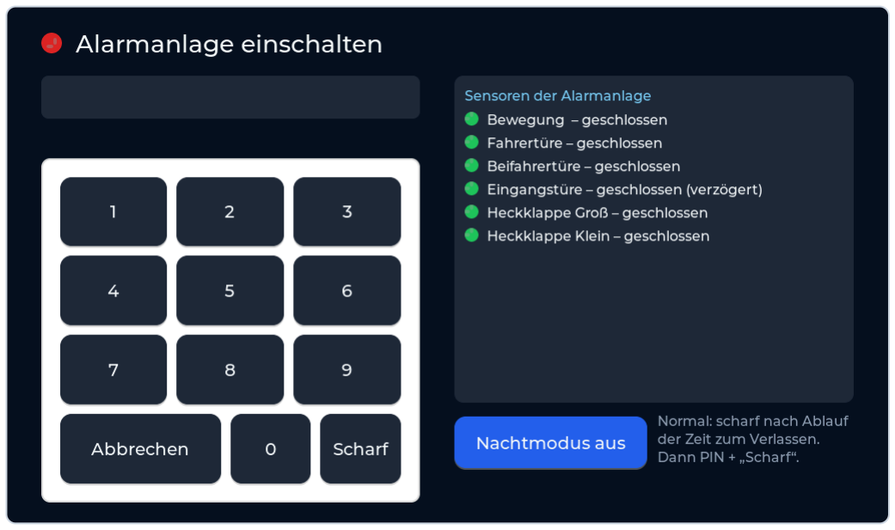
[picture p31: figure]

PIN-Dialog: links Ziffernblock, rechts die Sensoren, unten Nachtmodus

Die Alarmanlage überwacht Zigbee-Sensoren: Tür/Fenster, Bewegung und Wasser. Bis zu 12 Sensoren sind möglich. Tippe auf die Kachel Alarmanlage, um den PIN-Dialog zu öffnen:
Links ist der Ziffernblock. Die letzte Taste heißt Scharf oder Aus , je nach Zustand.
Rechts steht die Liste der Sensoren mit Farben:
grün: in Ordnung
rot: offen, Bewegung oder Alarm
gelb: Batterie schwach
grau: keine Verbindung oder im Nachtmodus ausgeblendet
Der Schalter Nachtmodus steht beim Öffnen immer auf „aus“ (blau). Auf „ein“ (grün) stellen, bevor du die PIN eingibst.

Scharf schalten

Modus | Verhalten
Normal | Die Anlage wird nach der Verlassenszeit scharf (30–120 s). Der Summer piept jede Sekunde, in den letzten 10 s doppelt, und beim Scharfwerden einmal lang.
Nachtmodus | Sofort scharf. Bewegungsmelder werden ignoriert, damit du dich im Fahrzeug bewegen kannst.

Normal scharf (nicht Nachtmodus): Während der Verlassenszeit bleibt das Display an und zeigt den Countdown. Sobald die Anlage scharf ist, wird die Wasserpumpe gesperrt (Symbol grau) und das Display geht 2 s später ganz aus – die Beleuchtung wird abgeschaltet, das spart Strom. Der Näherungssensor ruht. Eine Berührung weckt das Display jederzeit, danach gilt die eingestellte Ruhezeit. Beim Ausschalten der Anlage gilt wieder die vorherige Pumpeneinstellung. Im Nachtmodus bleiben Pumpe und Display wie gewohnt.

Ist beim Scharfschalten noch etwas offen oder ohne Verbindung, kommt ein Hinweis aufs Handy. Offene Kontakte werden erst überwacht, wenn sie einmal geschlossen wurden.

Auslösen
Sofort-Sensoren lösen direkt Alarm aus. Du bekommst eine Push-Nachricht mit dem Namen des Sensors.
Verzögerte Sensoren, zum Beispiel die Eingangstür, starten die Eingangszeit (30–120 s). Der Summer piept schnell. Wird in dieser Zeit nicht mit der PIN entschärft, löst der Alarm aus.
Sobald die Eingangszeit läuft oder der Alarm auslöst, wird das Display sofort hell und die PIN-Eingabe öffnet sich – zum schnellen Ausschalten.
Die Kachel zeigt den Countdown „Scharf in …“ bzw. „Alarm in …“ und den Namen des auslösenden Sensors.
Ein ausgelöster Alarm bleibt bestehen, bis die Anlage mit der PIN ausgeschaltet wird. Die Tür wieder zu schließen genügt nicht.

Sirene
Beim Auslösen laufen die unter Setup → Alarmanlage → Sirene gewählten Sirenen: der Ausgang der Steuerplatine (nur Steuerplatine V2) und/oder eine Zigbee-Sirene. Ein Alarmzyklus dauert 25–30 s (Vorgabe für Kfz-Alarmanlagen, ECE R116). Ein weiterer Zyklus startet nur bei einem erneuten Eingriff – also einer neuen Meldung eines Alarmsensors nach Ende des vorigen Zyklus –, insgesamt höchstens 10 Zyklen. Beim Ausschalten der Anlage mit der PIN verstummt die Sirene – eine Zigbee-Sirene mit Batterie nach wenigen Sekunden, weil sie Befehle nur alle 2–3 s abholt. Das Display wiederholt Ein- und Ausschaltbefehl dafür automatisch alle 3 s, damit keiner verloren geht; nach Ablauf der Zyklusdauer hört die Sirene von selbst auf.

PIN
Es gibt eine einzige 4-stellige PIN, ab Werk 0000. Sie gilt für die Alarmanlage und für die Setup-Sperre: Solange die Anlage an ist, öffnet sich das Setup nur mit PIN. Die PIN änderst du unter Setup → Alarmanlage.

Rauch- und Gasmelder gehören nicht zur Alarmanlage. Sie werden rund um die Uhr überwacht, auch wenn die Anlage aus ist.

## 4. Das Setup-Menü – Grundregeln

Das Setup öffnest du über das Zahnrad oben rechts. Links stehen die Kacheln in derselben Reihenfolge wie auf der Startseite, rechts die Systemeinstellungen.
Es gibt keine Speichern-Taste. Regler, Auswahllisten und Schalter speichern sofort. Textfelder speichern beim Schließen der Tastatur und beim Verlassen der Seite.
Test senden neben einem Grenzwert schickt sofort eine Probe-Nachricht aufs Handy. Kachelname: … rechts neben dem Titel ändert den Namen der Kachel (max. 20 Zeichen). Standard stellt den ursprünglichen Namen wieder her.
Die Farbauswahl unten in der Mitte ändert die Farbe der Kachel.
Abfrage-Intervall: wie oft ein Grenzwert geprüft wird. Melde-Intervall: Mindestabstand zwischen zwei Nachrichten bei anhaltender Überschreitung (1 / 6 / 12 / 24 / 48 / 60 Stunden, Standard 1 Stunde).
Zurück unten rechts führt zur vorherigen Seite.

## 5. Setup: Kacheln

Motor-Batterie / Aufbau-Batterie
Minimum und Maximum der Spannung mit Warnung, dazu Abfrage- und Melde-Intervall. Unten steht der aktuelle Messwert der Steuerplatine, jede Sekunde aktualisiert.

Frischwasser
Geber (Auswahl unten): Originalgeber (Stabsonde des LT 100, Standard) oder Ultraschall. Der Originalgeber geht nur mit der Steuerplatine V2 und den Jumpern J12/J13 rechts („ORIG“); sonst zeigt die Statuszeile einen Hinweis und das Display bleibt beim Ultraschall. Beim Originalgeber zeigt die Statuszeile den Zustand der vier Stäbe (trocken / feucht / nass).
Ultraschallsensor: Es funktionieren die üblichen wasserdichten Typen AJ-SR04M und JSN-SR04M-2 – ohne Löten, so wie sie geliefert werden. Ebenso geht ein wasserdichter Ultraschallsensor mit PWM-Ausgang (Typ A02YYPWM, Blindzone ca. 3 cm, Abstrahlwinkel ca. 60°). Die Steuerplatine misst jede Sekunde dreimal und mittelt. Die Steuerplatine erkennt die Betriebsart selbst (mit gebrückter R19 seriell, ohne Brücke Trigger/Echo); das dauert nach dem Einschalten bis zu 15 Sekunden.
Warnschwelle: Nachricht, wenn der Füllstand darunter fällt. Bei ausgeschalteter Pumpe (z. B. Fahrzeug abgestellt, Tank abgelassen) kommt keine Nachricht „Frischwasser leer“. Ohne Relaisplatine gilt die Warnung immer.
Tankinhalt bei 100 %: 50 bis 250 Liter in 5-Liter-Schritten (Standard 100). Die Kachel zeigt dann oben den Füllstand in Prozent und darunter die Literzahl.
Abgleich des Ultraschallsensors:
Bei leerem Tank beim Regler „Abstand bei leerem Tank“ auf Messwert tippen.
Bei vollem Tank dasselbe beim Regler „Abstand bei vollem Tank“.
Alternativ die Abstände in mm mit den Reglern einstellen: „leer“ 250 bis 500 mm, „voll“ 0 bis 150 mm. Der Wert für „leer“ muss größer sein als für „voll“.
Einbau: Die Sensorfläche mindestens 45 bis 55 mm (höchstens ca. 60 mm) über dem höchsten Wasserstand anbringen, in der Mitte der Öffnung, ohne Kragen oder Wand um die Fläche. Den Wandler mit einem Gummi- oder Silikonring im Halter entkoppeln. Am besten „voll“ abgleichen, wenn das Wasser am Überlauf steht.
Die Statuszeile unten zeigt jede Sekunde den Füllstand und den gemessenen Abstand in mm.

Abwasser
Warnschwelle: Nachricht, wenn der Füllstand sie übersteigt. Die Anzeige springt in Stufen 0/25/50/75/100 %. Die Statuszeile zeigt für jeden Stab „nass“, „feucht“ oder „trocken“ und die gemessene Spannung.

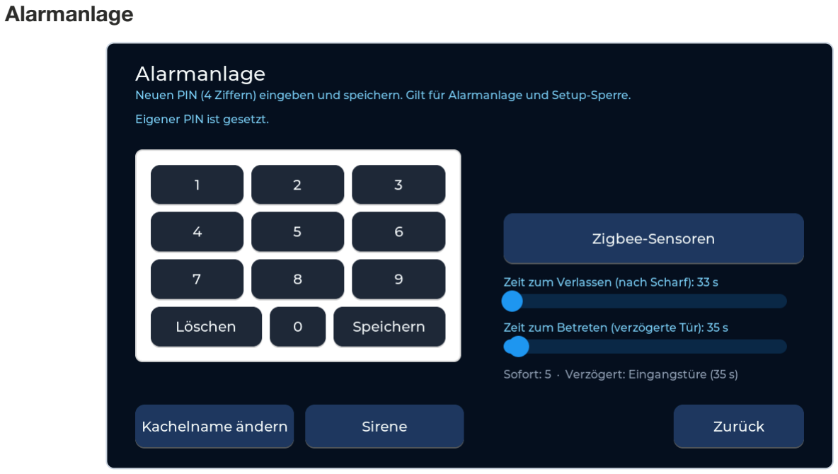
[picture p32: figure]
Alarmanlage

Setup Alarmanlage: PIN, Verlassens- und Eingangszeit, Zigbee-Sensoren, Sirene

Neue PIN eingeben (4 Ziffern).
Verlassens- und Eingangszeit einstellen (30–120 s).
Zigbee-Sensoren : Für jeden Sensor festlegen, ob er sofort oder verzögert auslöst oder nicht zur Anlage gehört.
Sirene :
Ausgang Steuerplatine an/aus. Nur schaltbar, wenn eine Steuerplatine V2 erkannt ist. Nur dann wird der Ausgang auch auf Kurzschluss und offene Leitung überwacht.
Zigbee-Sirene: Zigbee-Sirenen, Rauchmelder mit Sirenenfunktion oder eine Zigbee-Steckdose mit angeschlossener Sirene. Getestet und kompatibel: frient SMSZB-120 (Rauchmelder mit Sirene, Batterie) – er meldet weiter Rauch und dient gleichzeitig als Alarmsirene. Einfache Rauchmelder (z. B. Tuya TS0205) und Sirenen mit herstellereigenem Protokoll (z. B. Aqara, Heiman) können das nicht.
Dauer je Alarmzyklus 25–30 s und Wiederholung bei erneutem Eingriff (keine bis 9, zusammen höchstens 10 Zyklen).
Test 5 s lässt alle gewählten Sirenen 5 s ertönen. Die Taste wird dabei orange („Läuft …“) und ist bis zum Ende gesperrt. Eine Zigbee-Sirene mit Batterie setzt erst nach 2–3 s ein – einmal tippen genügt.
Der farbige Kasten unten zeigt die erkannte Platine: grün „Steuerplatine V2: Sirenenausgang vorhanden“, orange „Steuerplatine V1: kein Sirenenausgang – nur Zigbee“, grau „nicht erkannt“.

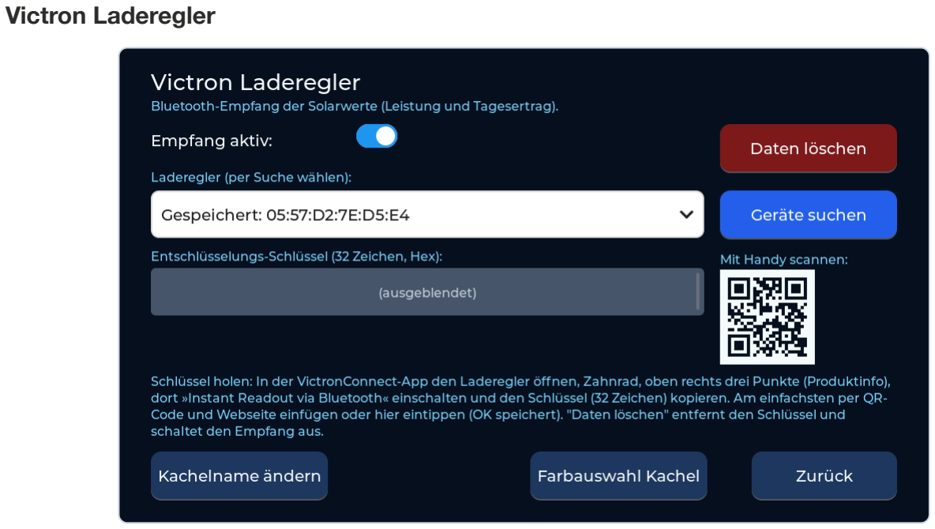
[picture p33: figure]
Victron Laderegler

Setup Victron: Gerät wählen, Schlüssel eintragen oder per QR-Code am Handy (Schlüssel im Bild ausgeblendet)

1. Geräte suchen und den Laderegler auswählen.
2. Den Entschlüsselungs-Schlüssel eintragen (32 Zeichen). Du findest ihn in der VictronConnect-App unter Produkt-Info → „Instant Readout“.
3. Bequemer: den QR-Code „Mit Handy scannen“ nutzen und den Schlüssel am Handy einfügen (Abschnitt 8).
Empfang aktiv schaltet die Abfrage an und aus. Daten löschen entfernt die Zuordnung.

Gas (Mopeka)
Sensoren suchen : sucht bis zu 90 s und ordnet die ersten zwei gefundenen Sensoren den Flaschen 1 und 2 zu. Nah an die Flaschen gehen, weil die Sensoren nur wenige Meter weit funken. Über die Auswahllisten lässt sich die Zuordnung tauschen. Adresse und Höhe sind dieselben wie in der Mopeka-App unter „Additional info“. Tipp: Den Knopf am Sensor drücken, dann steht er oben in der Liste.
Zuordnung löschen entfernt beide Sensoren. Bluetooth-Empfang aktiv schaltet beide Flaschen an und aus.
Weitere Parameter :
Flaschengröße sowie Höhe für voll und leer.
Abgleich über „App zeigt (%)“: Den Wert aus der Mopeka-App eingeben, das Display rechnet „voll“ passend um.
Füllstand-Warnung, wenn alle Flaschen darunter fallen (0 = aus).
Batterie-Warnung für die Sensoren.

JK-BMS (Aufbau-Batterie)
Mit JK-BMS suchen das BMS finden oder die Bluetooth-Adresse eintragen. Das Passwort ist ab Werk 123456. Dazu kommen die Warnung bei niedrigem Ladezustand, das Abfrage-Intervall und der Schalter Bluetooth-Empfang aktiv. Die Kachel zeigt eine Detailseite mit allen 12 Zellen, Temperaturen und dem Zustand von Laden, Entladen und Balancer.

Temperatur innen / außen / Kühlschrank
Den Sensor für die Kachel auswählen – einen Zigbee-Sensor oder einen fest verbauten Fühler „Fest verbaut 1, 2 …“ (DS18B20 an der Steuerplatine, in Klammern die aktuelle Temperatur zum Erkennen) –, Grenzwerte „unter“ und „über“ für Push-Nachrichten einstellen und eine Farbe wählen. „Temperatur innen“ hat zwei Auswahlfelder: Wohnbereich und Schlafbereich; die Grenzwerte gelten für beide. Der Tuya-Zigbee-Sensor mit Außenfühler (TS0601, _TZE284_8se38w3c) wird unterstützt: Er liefert Temperatur des Außenfühlers (sonst die Innentemperatur) und Luftfeuchte. Die festen Fühler werden über ihre Seriennummer zugeordnet – es ist egal, an welcher Klemme sie stecken. Mehrere Fühler dürfen auch zusammen an einer Klemme hängen.

Rauch- / Gasmelder
Bis zu zwei Zigbee-Melder auswählen und die Batterie-Warnung einstellen. Bei Rauch oder Gas kommt jederzeit „ALARM Rauch/Gas“ aufs Handy, danach „Entwarnung“.

## 6. Setup: System

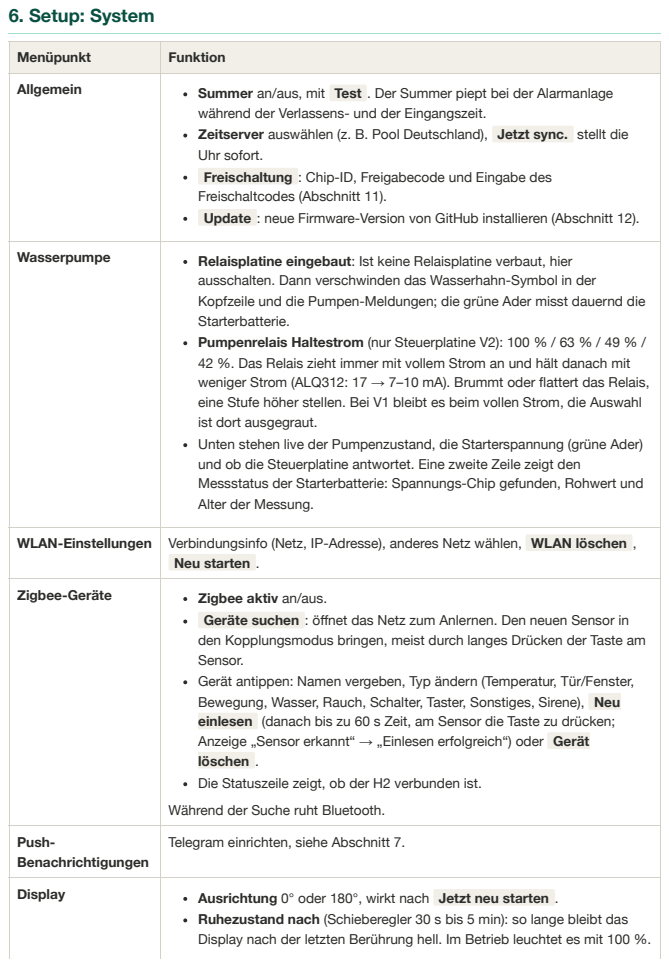
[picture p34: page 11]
Wasserpumpe; Relaisplatine eingebaut: Ist keine Relaisplatine verbaut, hier; Display; Ausrichtung 0° oder 180°, wirkt nach Jetzt neu starten .

Menüpunkt | Funktion

Allgemein | Summer an/aus, mit Test . Der Summer piept bei der Alarmanlage während der Verlassens- und der Eingangszeit. Zeitserver auswählen (z. B. Pool Deutschland), Jetzt sync. stellt die Uhr sofort. Freischaltung : Chip-ID, Freigabecode und Eingabe des Freischaltcodes (Abschnitt 11). Update : neue Firmware-Version von GitHub installieren (Abschnitt 12).

ausschalten. Dann verschwinden das Wasserhahn-Symbol in der
Kopfzeile und die Pumpen-Meldungen; die grüne Ader misst dauernd die
Starterbatterie.
Pumpenrelais Haltestrom (nur Steuerplatine V2): 100 % / 63 % / 49 % /
42 %. Das Relais zieht immer mit vollem Strom an und hält danach mit
weniger Strom (ALQ312: 17 → 7–10 mA). Brummt oder flattert das Relais,
eine Stufe höher stellen. Bei V1 bleibt es beim vollen Strom, die Auswahl
ist dort ausgegraut.
Unten stehen live der Pumpenzustand, die Starterspannung (grüne Ader)
und ob die Steuerplatine antwortet. Eine zweite Zeile zeigt den
Messstatus der Starterbatterie: Spannungs-Chip gefunden, Rohwert und
Alter der Messung.

WLAN-Einstellungen | Verbindungsinfo (Netz, IP-Adresse), anderes Netz wählen, WLAN löschen , Neu starten .

Zigbee-Geräte | Zigbee aktiv an/aus. Geräte suchen : öffnet das Netz zum Anlernen. Den neuen Sensor in den Kopplungsmodus bringen, meist durch langes Drücken der Taste am Sensor. Gerät antippen: Namen vergeben, Typ ändern (Temperatur, Tür/Fenster, Bewegung, Wasser, Rauch, Schalter, Taster, Sonstiges, Sirene), Neu einlesen (danach bis zu 60 s Zeit, am Sensor die Taste zu drücken; Anzeige „Sensor erkannt“ → „Einlesen erfolgreich“) oder Gerät löschen . Die Statuszeile zeigt, ob der H2 verbunden ist. Während der Suche ruht Bluetooth.

Push-Benachrichtigungen | Telegram einrichten, siehe Abschnitt 7.

Ruhezustand nach (Schieberegler 30 s bis 5 min): so lange bleibt das
Display nach der letzten Berührung hell. Im Betrieb leuchtet es mit 100 %.

Abdunkeln auf: Helligkeit im Ruhezustand. Die Hintergrundbeleuchtung wird wirklich heruntergeregelt, beim Ziehen am Regler sieht man die Helligkeit sofort.
Im Ruhezustand: Abdunkeln (Display bleibt schwach sichtbar, etwas mehr Verbrauch, z. B. am Landstrom) oder Ganz aus (Beleuchtung aus, sparsamste Einstellung). Eine Berührung weckt das Display immer, in jedem Zustand; der Näherungssensor weckt nur außerhalb von Nachtabschaltung und scharfer Alarmanlage.
Nachtabschaltung : im eingestellten Zeitfenster (z. B. 22:00 bis 06:00 Uhr) geht das Display nach der Ruhezeit ganz aus. Nachts weckt nur eine Berührung, nicht der Näherungssensor. Bei Alarm wird es immer hell. Nur mit gestellter Uhrzeit.
Systemfarben : Farben der Menüs und Tasten.
Näherungssensor : Wecken per Sensor an/aus und der Abstand (20– 150 cm). Steht jemand näher vor dem Display, wird es hell wie bei einer Berührung und bleibt hell, solange die Person davor steht. Das Display geht nach ca. 0,2 s an und bleibt nach dem Weggehen noch 5 s wach, danach gilt die Ruhezeit. Die Zeile „Messung jetzt“ zeigt den gemessenen Abstand zum Einstellen; darunter stehen die Rohwerte des Sensors (Status, Abstand, Signal, Umgebungslicht, Messungen der letzten 5 s) und seine Einstellungen – hilfreich bei der Fehlersuche.
Simulation | Testwerte für Batterien und Tanks eingeben, um Anzeige und Warnungen auszuprobieren. Nach einem Neustart gelten wieder die echten Werte.
System-Info | Kacheln ohne Scrollen: Laufzeit und letzter Neustart, interner RAM, PSRAM, Firmware, WLAN, Steuerplatine (V1/V2, Firmware-Version, verbunden) und Display (Zustand der Beleuchtung). Speicherwerte werden beim Öffnen der Seite gemessen. Licht-Test probiert nacheinander mehrere Helligkeitsstufen (je 3 s) und stellt danach wieder hell ein.

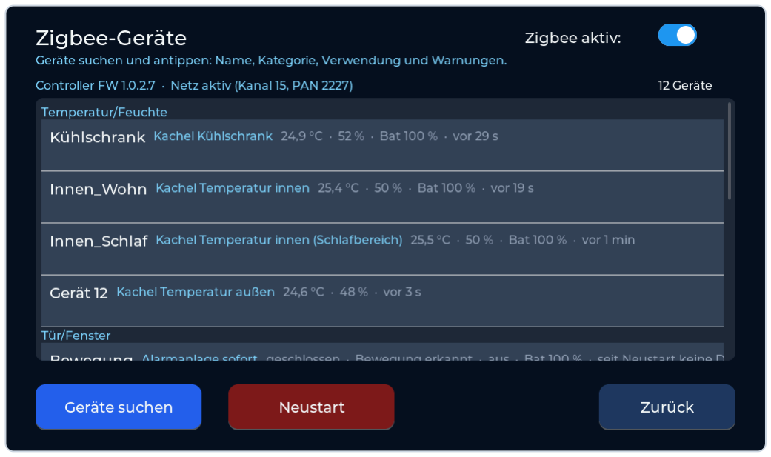
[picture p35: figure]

Zigbee-Geräte: nach Kategorien sortiert, mit Kachel, Messwerten, Batterie und letzter Meldung

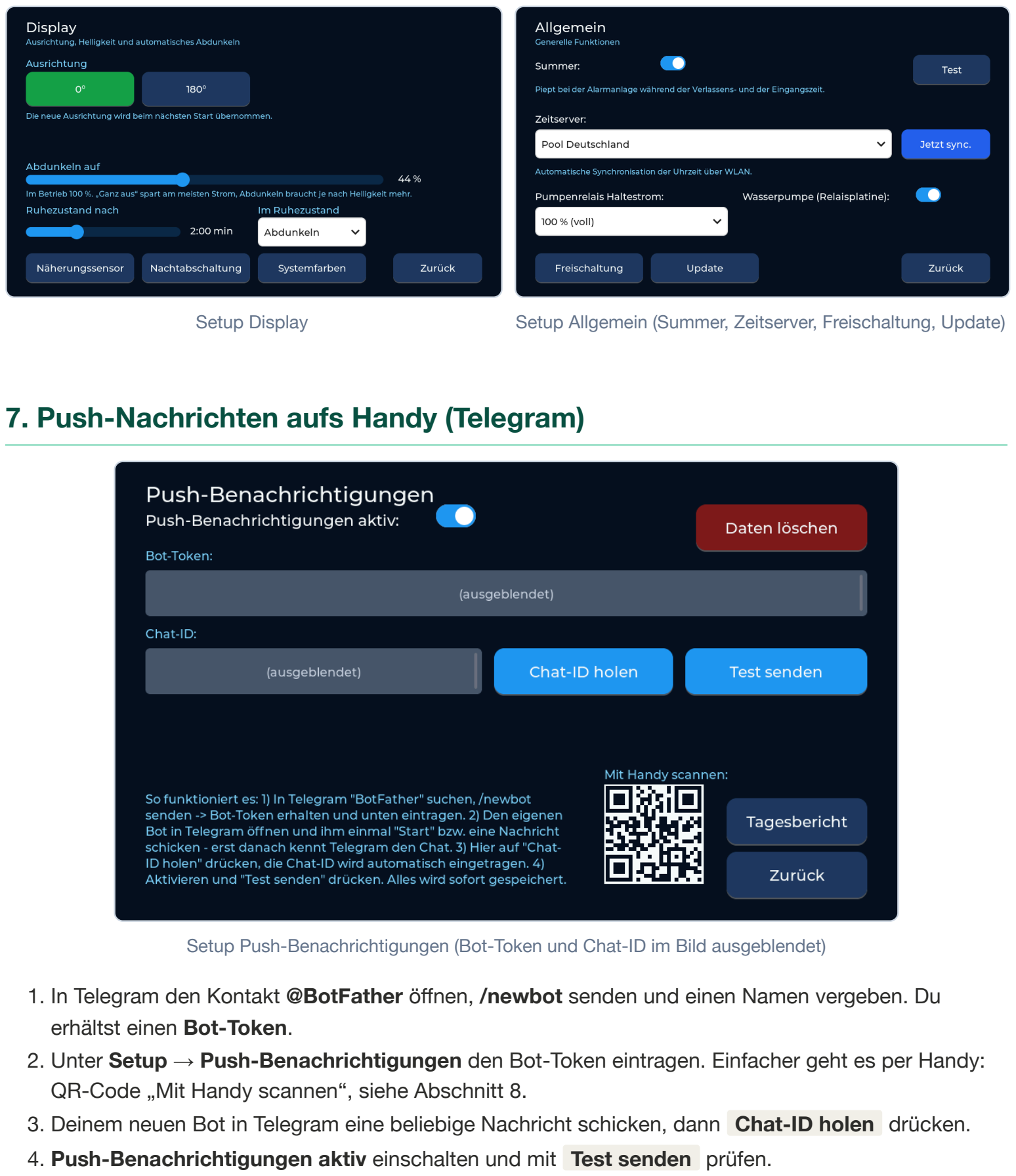
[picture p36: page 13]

Setup Display | Setup Allgemein (Summer, Zeitserver, Freischaltung, Update)

## 7. Push-Nachrichten aufs Handy (Telegram)

Setup Push-Benachrichtigungen (Bot-Token und Chat-ID im Bild ausgeblendet)

1. In Telegram den Kontakt @BotFather öffnen, /newbot senden und einen Namen vergeben. Du erhältst einen Bot-Token.
2. Unter Setup → Push-Benachrichtigungen den Bot-Token eintragen. Einfacher geht es per Handy: QR-Code „Mit Handy scannen“, siehe Abschnitt 8.
3. Deinem neuen Bot in Telegram eine beliebige Nachricht schicken, dann Chat-ID holen drücken.
4. Push-Benachrichtigungen aktiv einschalten und mit Test senden prüfen.

Nachricht | Wann
Tagesbericht | einmal am Tag zur eingestellten Uhrzeit (siehe unten)
ALARM: „Name“ hat ausgelöst! | Alarmanlage ausgelöst (sofort oder nach der Verzögerung)
Hinweis Alarmanlage: offen / ohne Verbindung | beim Scharfschalten
ALARM Rauch/Gas / Entwarnung | rund um die Uhr
Warnung Frischwasser / Abwasser | Warnschwelle unter- bzw. überschritten
Warnung Gas: Flasche fast leer | alle Flaschen unter der Grenze
Temperatur unter / über Grenzwert | je Temperatursensor
Batterie schwach | Zigbee-Sensoren, Gassensoren, JK-BMS-Ladezustand
„Name“ meldet sich seit … h nicht mehr | Alarm- oder Rauchmelder ohne Verbindung

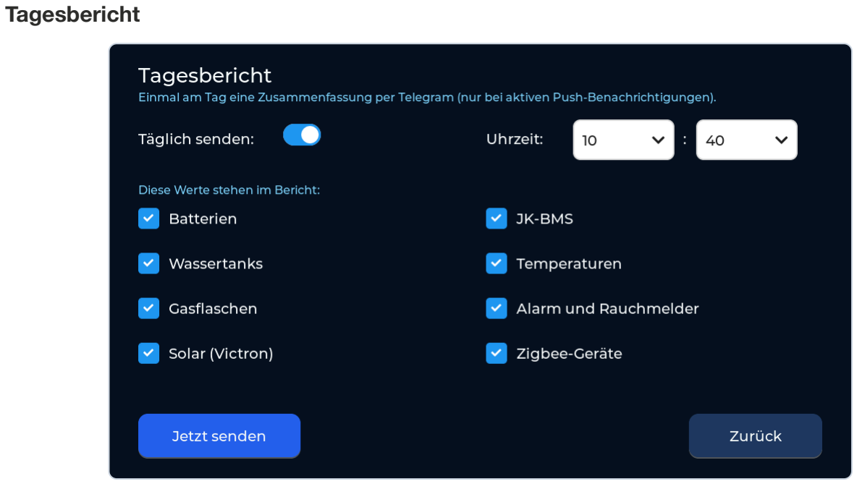
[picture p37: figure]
Tagesbericht

Setup Tagesbericht: Uhrzeit und Inhalte wählen

Auf der Seite Push-Benachrichtigungen führt Tagesbericht (über Zurück ) zur täglichen Zusammenfassung. Dort Täglich senden ein- oder ausschalten, die Uhrzeit wählen (5-Minuten-Schritte) und anhaken, was im Bericht stehen soll: Batterien, Wassertanks, Gasflaschen, Solar (Victron), JK-BMS, Temperaturen, Alarm und Rauchmelder, Zigbee-Geräte (offline oder Batterie schwach). Jetzt senden schickt den Bericht sofort zum Ausprobieren. Der Bericht kommt nur mit gestellter Uhr (WLAN/Zeitserver) und aktiven Push-Benachrichtigungen; war das Display zur Uhrzeit aus, wird er bis zu 30 Minuten später nachgeholt.
Daten löschen entfernt Token und Chat-ID.

## 8. Einstellen per Handy (Webseite)

Lange Schlüssel tippt man bequemer am Handy. Auf den Seiten Push-Benachrichtigungen und Victron zeigt das Display einen QR-Code „Mit Handy scannen“:
Scannen öffnet eine Webseite auf dem Display, zum Beispiel http://192.168.x.x/. Das Handy muss dafür im selben WLAN sein.
Dort Bot-Token, Chat-ID bzw. den Victron-Schlüssel eintragen und speichern.

Während einer Bluetooth-Suche ist die Webseite kurz nicht erreichbar.
Unter http://192.168.x.x/screenshot liefert das Display ein Bildschirmfoto der aktuellen Seite (praktisch für Fragen an den Support).

## 9. Display ausschalten

Die rote Taste ⏻ neben dem Datum öffnet die Abfrage „Display ausschalten?“. Nach dem Bestätigen geht das Display in den Tiefschlaf und die Beleuchtung wird abgeschaltet. Eine Berührung weckt es wieder, dabei startet es neu. Vor dem Tiefschlaf wird die Wasserpumpe ausgeschaltet und bleibt auch nach dem Aufwachen aus (Schutz, z. B. im Winter bei geleerten Leitungen) – bei Bedarf über den Wasserhahn-Knopf wieder einschalten. Die Steuerplatine ruht ebenfalls (Zigbee, Tanks, Spannungen) und startet beim Aufwachen neu; die Zigbee-Sensoren melden sich danach wieder.

Im Tiefschlaf überwacht das Display nichts: keine Alarmanlage, keine Push-Nachrichten.

## 10. Hilfe bei Problemen

Anzeige | Ursache / Abhilfe
Kachel zeigt „-- %“ | Kein gültiger Messwert. Die Statuszeile auf der Setup-Seite der Kachel zeigt die Ursache.
„Keine Antwort vom H2 (Tanksensoren)“ | USB-Kabel Display ↔ H2 prüfen: am Display Buchse „USB“, am H2 Buchse „UART“.
„Ultraschallsensor: kein Messwert“ | Verdrahtung Pins 11/12 und Versorgung 5V/G prüfen, Stecker der Sonde an der Sensorplatine prüfen. Die Sonde braucht eine Fläche (Wasser, Wand) in 25 cm (PWM-Typ: 3 cm) bis 6 m Abstand – ins Leere gerichtet gibt es keinen Messwert.
Abwasser zeigt falsche Stufe | Setup → Abwasser: Welcher Stab ist „nass“? Zuordnung der Adern zu Pin 1–4 prüfen.
Gasflasche „-- %“ | Sensor außer Reichweite oder Batterie leer. Suche nah an der Flasche wiederholen.
JK-BMS „Warte auf BMS-Daten…“ | Handy-App vom BMS trennen, Abstand verringern.
Meldung „Kein WLAN“ | Router bzw. Hotspot einschalten, oder unter WLAN-Einstellungen ein neues Netz einrichten.
Uhr zeigt „--:--“ | Kein WLAN. Setup → Allgemein → Jetzt sync.
Meldung „Steuerplatine nicht erreichbar“ | USB-Kabel Display ↔ H2 prüfen (Display „USB“, H2 „UART“) und 12 V an ST1.
Meldung „Sirene: Kurzschluss oder Leitung offen“ | Sirenenkabel an der Klemme „SIRENE“ prüfen. Die Sirene darf höchstens ca. 350 mA ziehen. Die Meldung kommt nur, wenn „Ausgang Steuerplatine“ eingeschaltet ist.
Wasserhahn lässt sich nicht einschalten | Alarmanlage scharf (Pumpe gesperrt) oder „Steuerplatine nicht gefunden“ – Steuerplatine und Relaisplatine prüfen.
„Näherungssensor antwortet nicht“ | Kabel am I2C-Anschluss (3V3, GND, SDA, SCL) prüfen. Die Funktion lässt sich unter Setup → Display → Näherungssensor ausschalten.
Display wird nicht hell, wenn man davor steht | Setup → Display → Näherungssensor: Abstand größer stellen, Loch im Rahmen frei halten. Der Sensor sieht nur geradeaus.
Näherungssensor misst unruhig oder nur ganz nah | Setup → Display → Näherungssensor: Sensor auf die Decke richten – ein gutes Modul zeigt einen ruhigen Abstand, und „Signal max“ steigt mit der Hand in 20 cm deutlich über 1 MCPS. Springt der Abstand stark oder bleibt „Signal max“ um 0,5, ist das Modul schlecht (bei günstigen VL53L0X-Modulen häufig) – ein anderes einsetzen.
Setup lässt sich nicht öffnen | Die Alarmanlage ist an: PIN eingeben.

## 11. Testzeit und Freischaltung

Beim ersten Start zeigt das Display die Seite Freischaltung mit Chip-ID und Freigabecode sowie der fertigen Zeile zum Freischalten, z. B. AA:BB:CC:DD:EE:FF 1234.
Test starten (72 Std.) : Das Display läuft 72 Betriebsstunden ohne Einschränkung. Ohne Strom steht die Zeit still. Die restliche Zeit steht oben im Meldungsfeld („Testversion: noch … Std.“).
Nach Ablauf der Testzeit startet das Display neu und zeigt nur noch die Freischalt-Seite. Freischaltcode bestellen: Zeile vom Display beim Bezahlen angeben (siehe Anleitung auf GitHub) oder per E-Mail an wohnmobil.display@gmail.com schicken. Der 6-stellige Code kommt per E-Mail. Code rechts über den Ziffernblock eingeben und mit OK bestätigen. Während der Testzeit erreichst du die Seite über Setup → Allgemein → Freischaltung.
Der Code gilt für dieses Display für immer – auch nach Updates oder einer Neuinstallation.

Nach jeder dritten falschen Eingabe ist die Eingabe für einige Stunden gesperrt (3, 6, 12, höchstens 24 Stunden).

## 12. Updates

Freigeschaltete Displays holen neue Versionen über WLAN – für das Display und für die Steuerplatine: Setup → Allgemein → Update.
Oben stehen die installierten Versionen („Display 1.0.7 · Steuerplatine 1.0.3.0“). Beim Öffnen sucht die Seite bei GitHub nach neuen Versionen und zeigt, was sich geändert hat.
Installieren : Das Display startet neu in einen Update-Modus (nur Anzeige, WLAN und die Verbindung zur Steuerplatine). Zuerst wird bei Bedarf die Steuerplatine über das USB-Kabel aktualisiert, danach das Display. Das dauert 1–3 Minuten; danach startet alles normal.
Währenddessen nichts ausschalten oder ausstecken.
Alle Einstellungen, Sensoren, das Zigbee-Netz und die Freischaltung bleiben erhalten.
Startet eine neue Display-Version nicht richtig, kehrt das Display beim nächsten Start automatisch zur vorherigen Version zurück. Bricht das Update der Steuerplatine ab, einfach erneut auf Installieren tippen – die Steuerplatine lässt sich immer neu bespielen, auch wenn sie nicht mehr antwortet („Steuerplatine nicht verbunden“).

## 13. Druckteile (3D-Druck)

Die Druckdateien (STL) liegen auf GitHub im Ordner druck: github.com/Wohnmobil-Display/Wohnmobil-Display.
Rahmen für das Display: Damit ersetzt das Display das alte LT-100-Panel – der fertige Rahmen passt in den vorhandenen Ausschnitt. Es gibt ihn mit Aufnahme für den Näherungssensor und ohne Sensor. Beim Drucken Stützstruktur verwenden.
Halter für Türkontakte: je ein Halter für Sensor und Magnet, in mehreren Sockelhöhen zum Ausgleich unterschiedlicher Abstände an Tür und Rahmen. Die Standard-Variante (2-mm-Boden) wird geklebt, die Varianten mit höherem Sockel können geklebt oder geschraubt werden.
Gehäuse für Steuerplatine und Relaisplatine.

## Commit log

2026-09-27 Bedienungsanleitung mit Bildschirmfotos, Bildergalerie in der Anleitung
2026-09-27 Anleitung: Überwachung und Benachrichtigungen in den Vordergrund
2026-09-28 Druckdateien für Steuer- und Relaisgehäuse, Foto Frischwassertank entfernt
    [relaisplatine_v2_deckel.stl, relaisplatine_v2_unterschale.stl, steuerplatine_v2_deckel.stl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]
2026-09-28 Anleitung: Steuerplatine und Relaisplatine ausführlich, Pumpe abschaltbar
2026-09-28 Installer: Steuerplatine (ESP32-H2), Anleitung: Update der Steuerplatine über das Display
2026-09-28 Neue Startseiten-Ansicht, Bedienungsanleitung: Updates für Display und Steuerplatine
2026-09-28 Bedienungsanleitung: Näherungssensor und Sirene (frient SMSZB-120) aktualisiert
2026-09-29 Druckdatei: Rahmen für das Display
    [display_rahmen.stl]
2026-09-29 Druckdateien: Türkontakt-Halter (7-mm-Sockel und Standard)
    [tuerkontakt_magnethalter_7mm_sockel.stl, tuerkontakt_magnethalter_standard.stl, tuerkontakt_sensorhalter_7mm_sockel.stl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]
2026-09-29 Druckteile: Türkontakt-Halter (Standard, 5-mm-Sockel), Hinweis Stützstruktur beim Display-Rahmen; Anleitung: Abschnitt Druckteile
    [tuerkontakt_magnethalter_5mm.stl, tuerkontakt_magnethalter_standard.stl, tuerkontakt_sensorhalter_5mm.stl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]
2026-09-29 Druckteile: Display-Rahmen mit und ohne Näherungssensor
    [display_rahmen_mit_sensor.stl, display_rahmen_ohne_sensor.stl]
2026-09-29 Hardware: Zeichnungen Ultraschallsensor an ST2 und Summer/Näherungssensor am Display, Systemübersicht mit Näherungssensor
2026-09-29 Druckteile: Türkontakt-Halter mit 10 mm Abstand
    [tuerkontakt_magnethalter_10mm.stl, tuerkontakt_sensorhalter_10mm.stl]
2026-09-30 Installation: zwei klare Knöpfe/Links für Display und Steuerplatine (H2), Sprungmarken #display und #steuerplatine
2026-09-30 Installation: Anschluss-Skizze Display/Steuerplatine, Hinweis Jumper J5, Buchse UART1
2026-09-30 Installation: Draufsicht Display-Rückseite und H2-Board mit Buchsen, Schalter UART1 und Jumper J5
2026-10-01 Einkaufsliste: Crimpstifte (EBL Block 5 Pin 3, 12 V Dauer), USB-C-Datenkabel, Schrauben M3x8
2026-10-01 Einkaufsliste: Crimpstifte durch MATE-N-LOK 6-polig Steckverbinder-Set ersetzt (EBL Block 5 Pin 3)
2026-10-07 Anleitung: Liter-Anzeige, Tankeinstellungen, PWM-Ultraschallsensor, Pumpen-Diagnose
2026-10-14 Frischwasser: Originalgeber oder Votronic Tankfuehler 5545, Ultraschall entfernt; Anleitung und Einkaufsliste aktualisiert
2026-10-14 Relaisplatine V2: Bestueckung und Fertigungsdaten, Gehaeusezeichnung V2, Testzeit entfernt (Anleitung, README, Installer-Seite)
2026-10-14 Anleitung: Bilder zu Steckbruecken J12/J13 und Platinenuebersicht V2
2026-10-14 README: Steuerplatine aus Restbestand (9 Stueck, Selbstkostenpreis), Tuerkontakt-Halter STL
2026-10-14 Steuerplatine V2: Fertigungsdaten (Gerber, Stueckliste, Bestueckung), Link im Restbestand-Abschnitt
2026-10-14 README: Naeherungssensor optional, Rahmen ohne Sensor
2026-10-14 Screenshot Alarmanlage: altes Bild mit Sensoren wiederhergestellt
2026-10-14 Hinweis: Hobbyprojekt, Eigenverantwortung und Haftung ausfuehrlicher
2026-10-14 Screenshot Alarmanlage einschalten: altes Bild mit allen Sensoren wiederhergestellt
2026-10-14 Gruene Ader durchverbinden, Block-5-Stift, Tankdeckel- und Tankfuehler-Bilder; Anleitung
2026-10-18 Tankdeckel: Abstand zum Boden mind. 1 cm, Foto mit TPU-Dichtung
2026-10-18 Bilder und Zeichnungen in Unterordner sortiert (bilder/tankdeckel, druck/zeichnungen)
2026-10-20 Votronic-Anschluss und Abwasser ST3 korrigiert
2026-10-21 Pumpe über Relaisplatine (Block 3 Pin 8, Block 8 Pin 9) mit Schaubild und Fotos, Block 5 entfernt, Sonoff-Sirene in Einkaufsliste
2026-10-22 Tiefschlaf und 12-V-Hauptschalter (EBL aus wie am LT 100) in Anleitung und README
2026-10-22 Pumpe: Sicherung 5 A bei Block 8 Pin 9 (README, Anleitung, Schaubild)
2026-10-22 Restplatinen: Preisrechnung vereinfacht (306,80 EUR / 10 = 30,68 EUR); Amazon-Link Temperaturfuehler DS18B20
2026-10-22 Freischalten: klar erklaert, was gesperrt ist (nur Sperrbildschirm, keine Testzeit) und was der Code bringt
2026-10-22 Freischalten: nur Bediensoftware kostenpflichtig, alles andere und alle Updates frei
